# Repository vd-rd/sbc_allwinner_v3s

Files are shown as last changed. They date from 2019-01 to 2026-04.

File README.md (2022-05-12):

# Allwinner V3s SBC

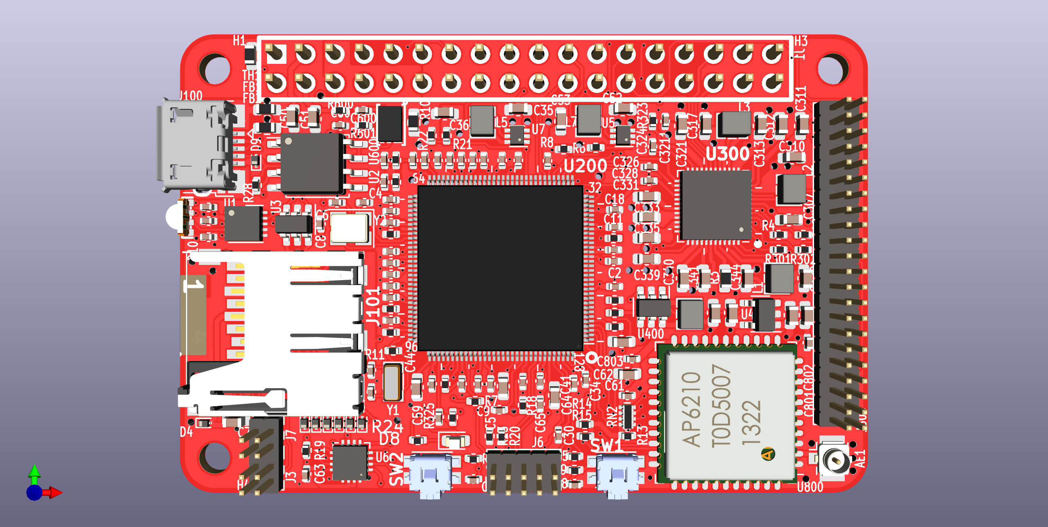
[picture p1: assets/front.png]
board_render


This board embeds a SIP (single core 1GHz Cortex-A7 with 64MB DDR2) with AXP203 PMIC, IO headers and microSD/eMMC storage.

Board overview (draft):
[TBD]

## Board features
| Characteristic | Description |
| --- | --- |
| Dimensions | 60mm x 40mm |
| Processor | Allwinner V3s Cortex-A7 @1GHz |
| Oscillators | 32.768kHz slow click, 24MHz main clock |
| RAM | 512Mb embedded DDR2 memory |
| Storage | SPI Flash/microSD |
| USB | 1 microUSB OTG |
| Ethernet | 10/100M PHY with pins on header |
| Supply | Power path between USB/Vin/Battery, 5V max |

## Notes and observations

### Expansions
The board features a number of connectors. They expose various buses for expansions:
 * 1 SPI port
 * 2 UART ports
 * 1 I2C port
 * 2 ADC enabled pins
 * 18bit parallel LCD interface
 * Ethernet signals with status LEDs

The connectors are organized in consistent locations present on the other SBCs i have developed.
 * J100 connector - 2.54mm 2x18 header with standard Apollo IoT pinout
 * J200 connector - 1.27mm 2x04 header with ethernet signals
 * J300 connector - 1.27mm 2x05 header with analog audio I/O signals
 * J500 connector - 1.27mm 2x20 header with parallel LCD interface signals

Check expansions section for example daughter cards with added functionality

### Boot process
The board has two boot strategies depending on component configuration. If the SPI flash memory is not used, the BROM uses the MicroSD as boot source and loads UBoot from there.
If the SPI flash is populated, UBoot with a minimal Kernel and Busybox can be stored as recovery environment or main application.

### LCD connector
Most of port D signals are mapped to the LCD connector. if LCD is not used they can be muxed as GPIO or other functions upon editing the DT overlay.

### AXP203
AXP203 is pin to pin compatible with the more popular AXP209, so they can be easily swapped.

### 1.2V Rail
Two different 1.2V rails are provided to the CPU. This is a deliberate decision to allow fixed CPU internal rail at 1.2V and provide DVFS cappability to 1.2V rail for CPU core.

### Signals on headers
All the signals on the headers, with their initial functions are detailed on the silkscreen on the bottom layer

### Battery usage
The board schematic uses a Diodes AP9211 battery protection IC for safety protections when used toghether with a LiIon battery. If a battery pack with embedded protection and thermistor is used, TH1 and AP9211 can be left unpopulated.

### Expansions
 The board can be combined with several predefined capes that add functionality.
 * [LCD cape](https://github.com/vd-rd/hw_cape_lcd) can be used to add a 3inch LCD/Touch with 800x480px resolution.
 * [GPS cape](https://github.com/vd-rd/hw_cape_gps) adds GPS/GNSS/GLONAS capabilities
 * [GSM cape](https://github.com/vd-rd/hw_cape_gsm) adds GPRS connectivity. 

## Resources
You can find all necesary information to build or evaluate the module here:
   - [View 3D board render](https://a360.co/2GTPupk)
   - [Fabrication files](https://github.com/vd-rd/sbc_alw_v3s/releases)

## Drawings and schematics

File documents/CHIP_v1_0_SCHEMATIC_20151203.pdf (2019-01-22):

# Schematics Index：

# P01: REVISION HISTORY

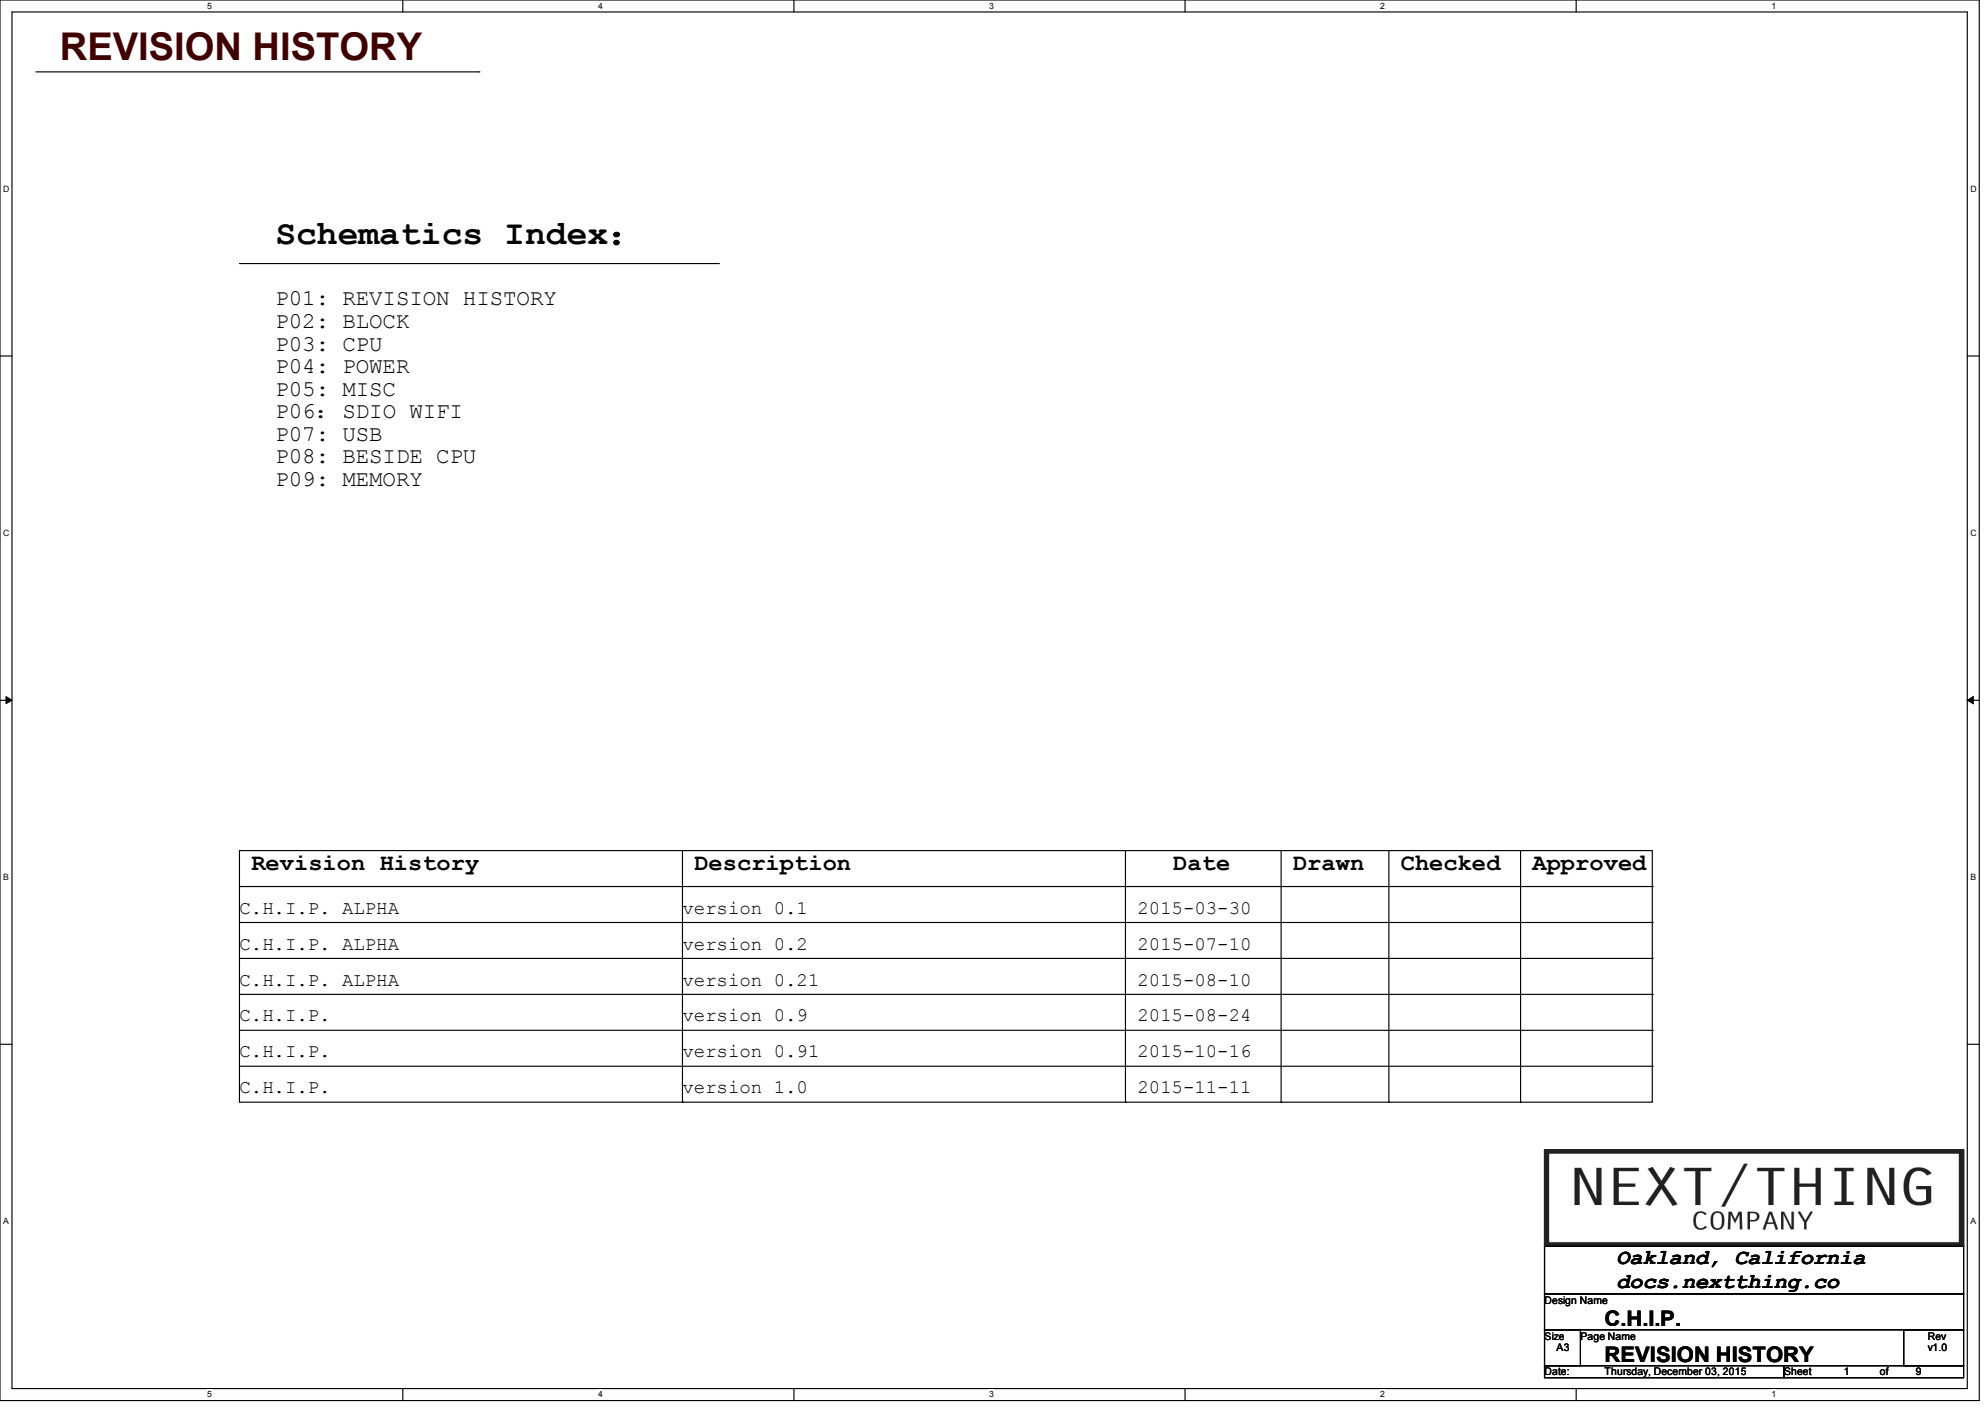
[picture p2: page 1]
Revision History; Description; Date; Drawn; Checked; Approved; P02: BLOCK P03: CPU P04: POWER P05: MISC P06：SDIO WIFI; P07: USB P08: BESIDE CPU P09: MEMORY; REVISION HISTORY; C.H.I.P. ALPHA; version 0.1; version 0.2; version 0.21; version 0.9; version 0.91; version 1.0; Design Name; Size; Page Name; Rev; Date:; Sheet; Thursday, December 03, 2015

Oakland, California
docs.nextthing.co

# BATT

# DCIN

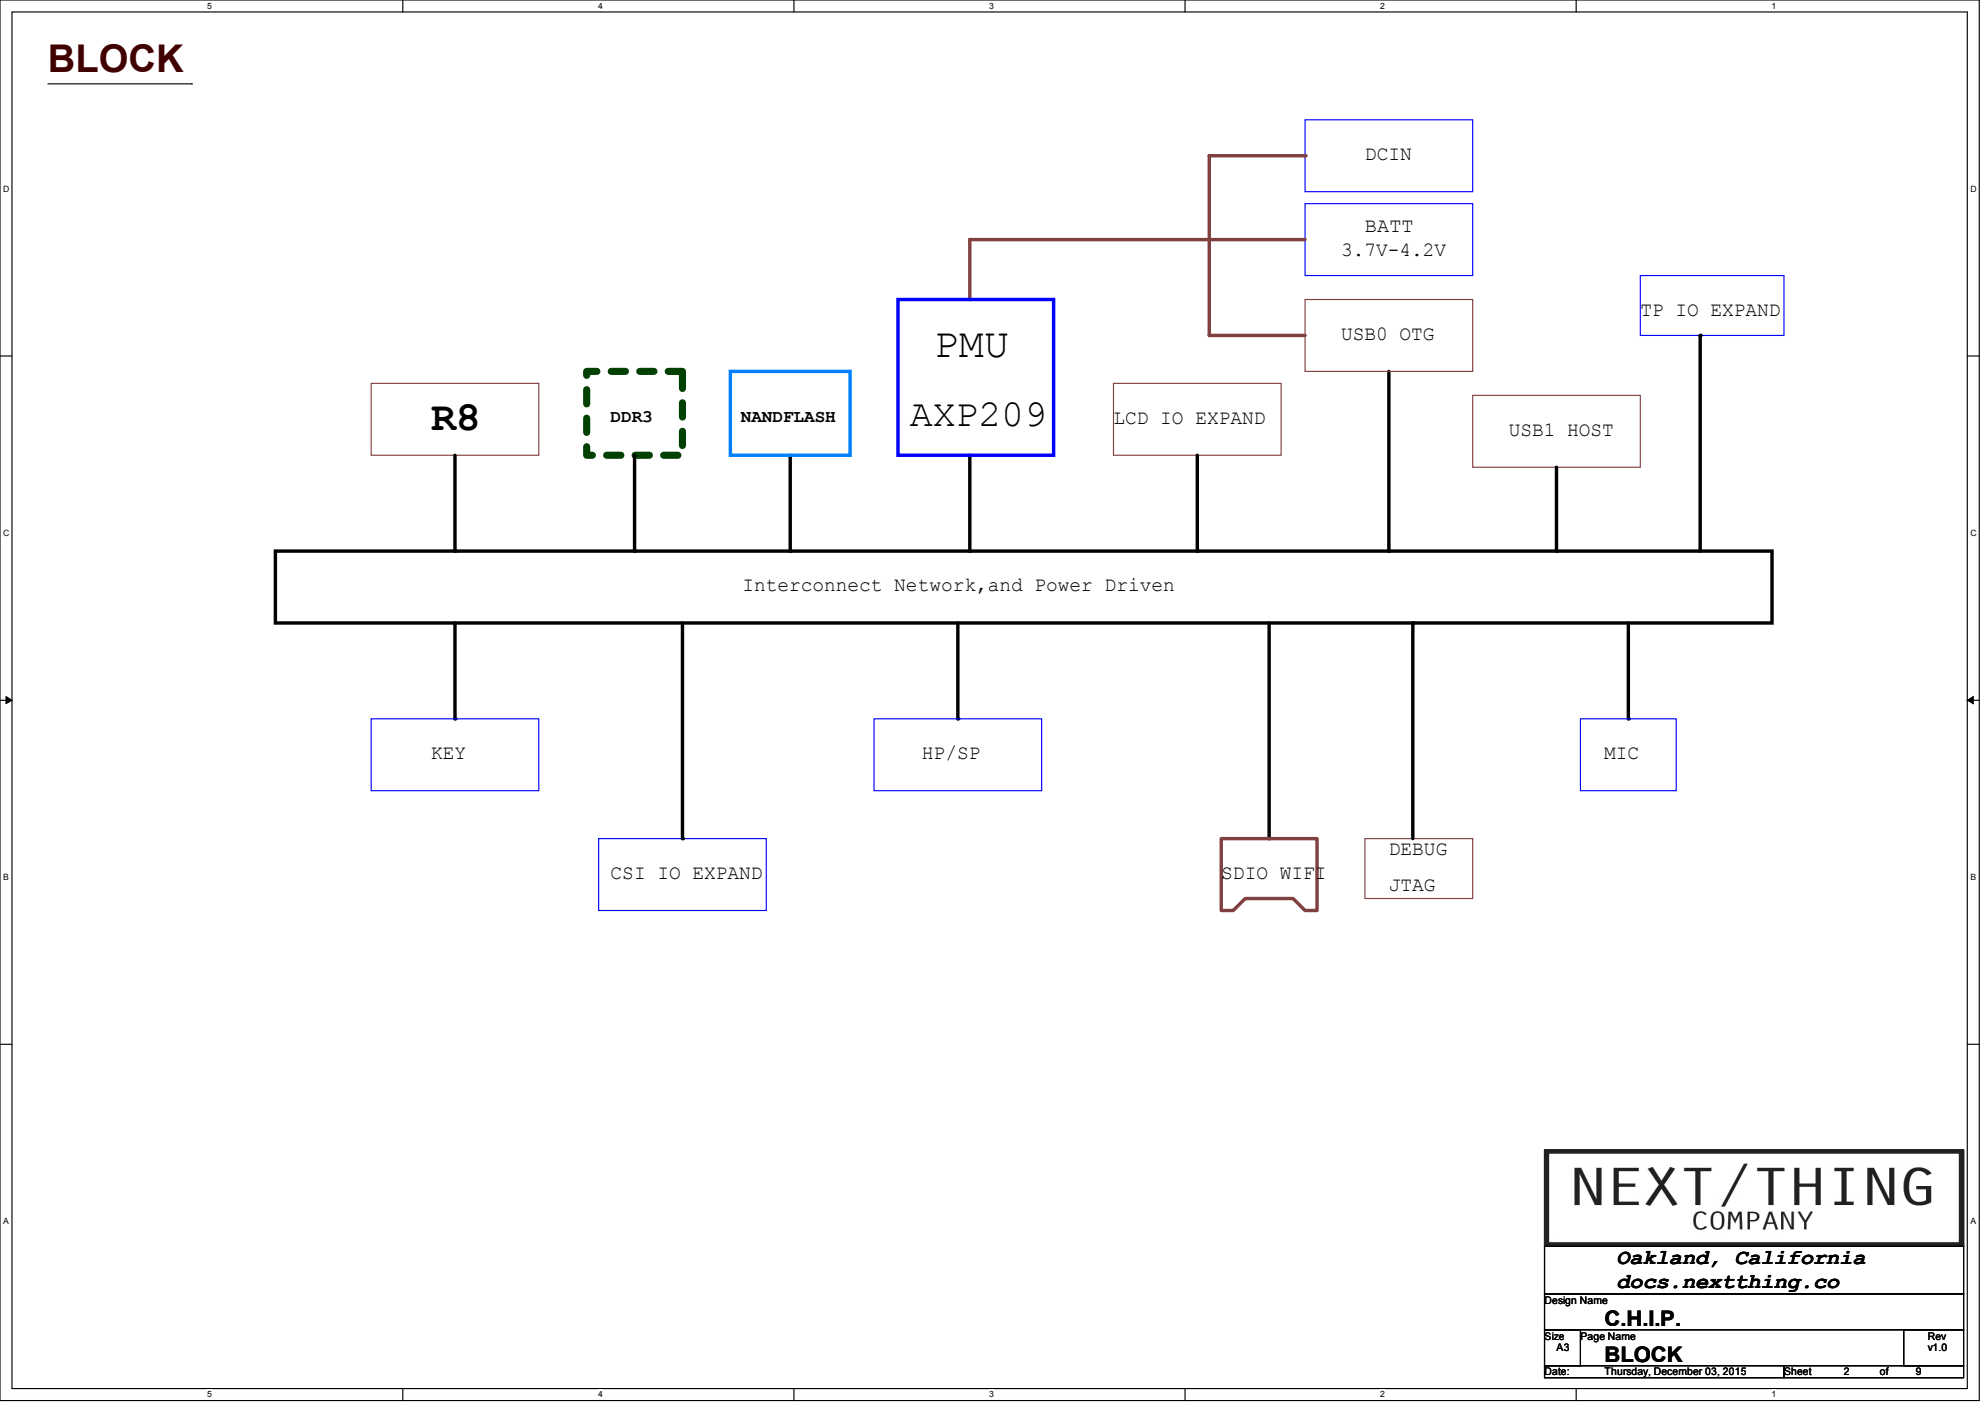
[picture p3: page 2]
SDIO WIFI; USB0 OTG; DEBUG; JTAG; KEY; PMU; AXP209; MIC; BLOCK; NANDFLASH; USB1 HOST R8; DDR3; Thursday, December 03, 2015

TP IO EXPAND

LCD IO EXPAND

Interconnect Network,and Power Driven

CSI IO EXPAND

Oakland, California
docs.nextthing.co

# CPU

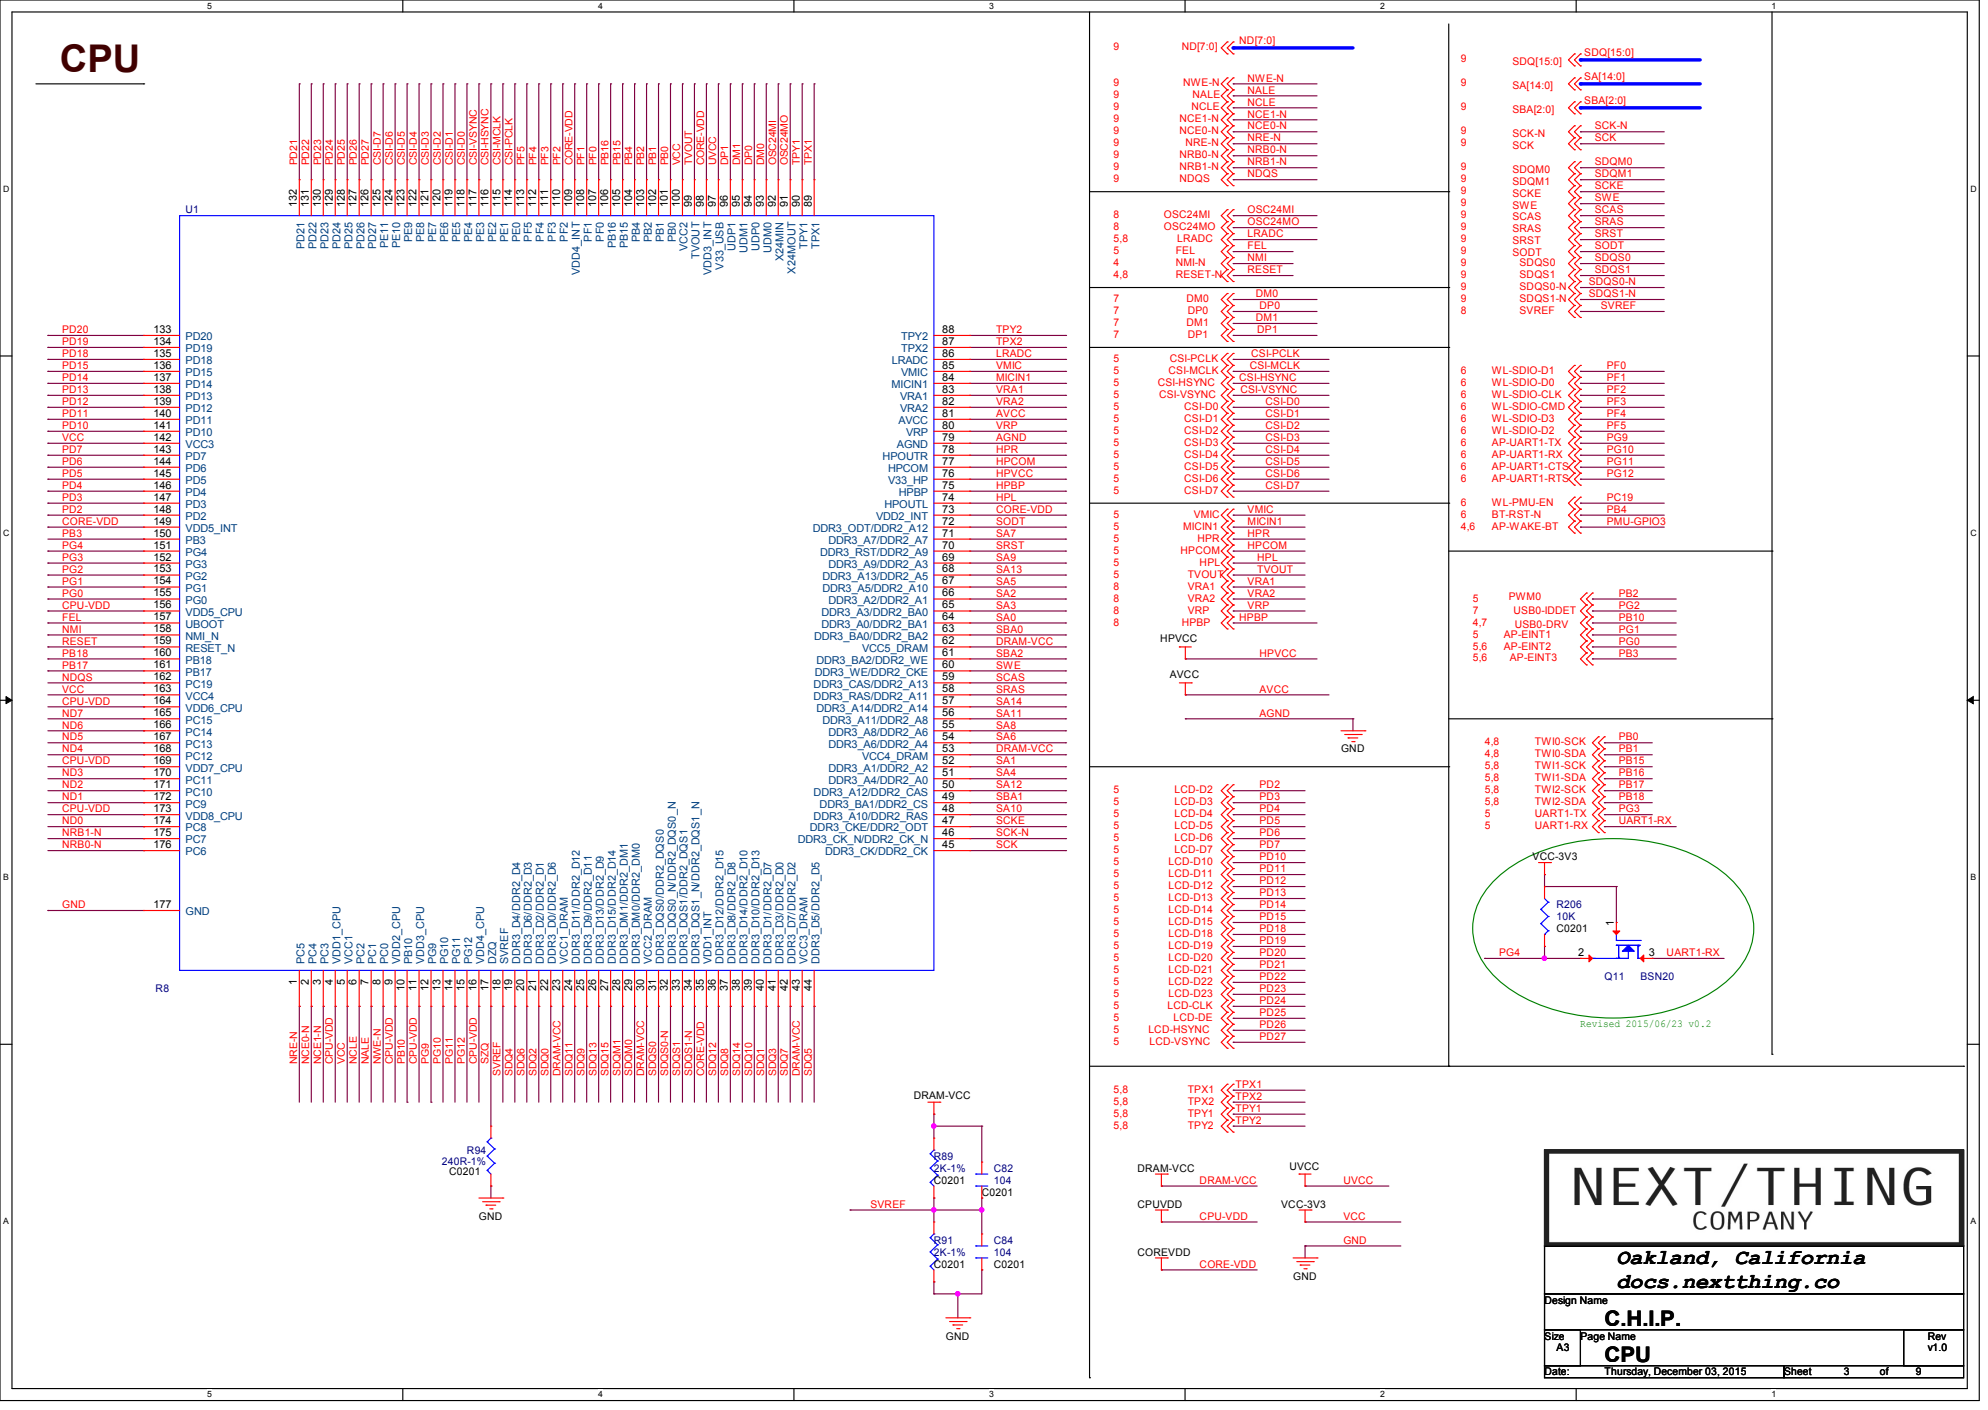
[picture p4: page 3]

# POWER/PMU

# IPSOUT TO 5V FOR SYS

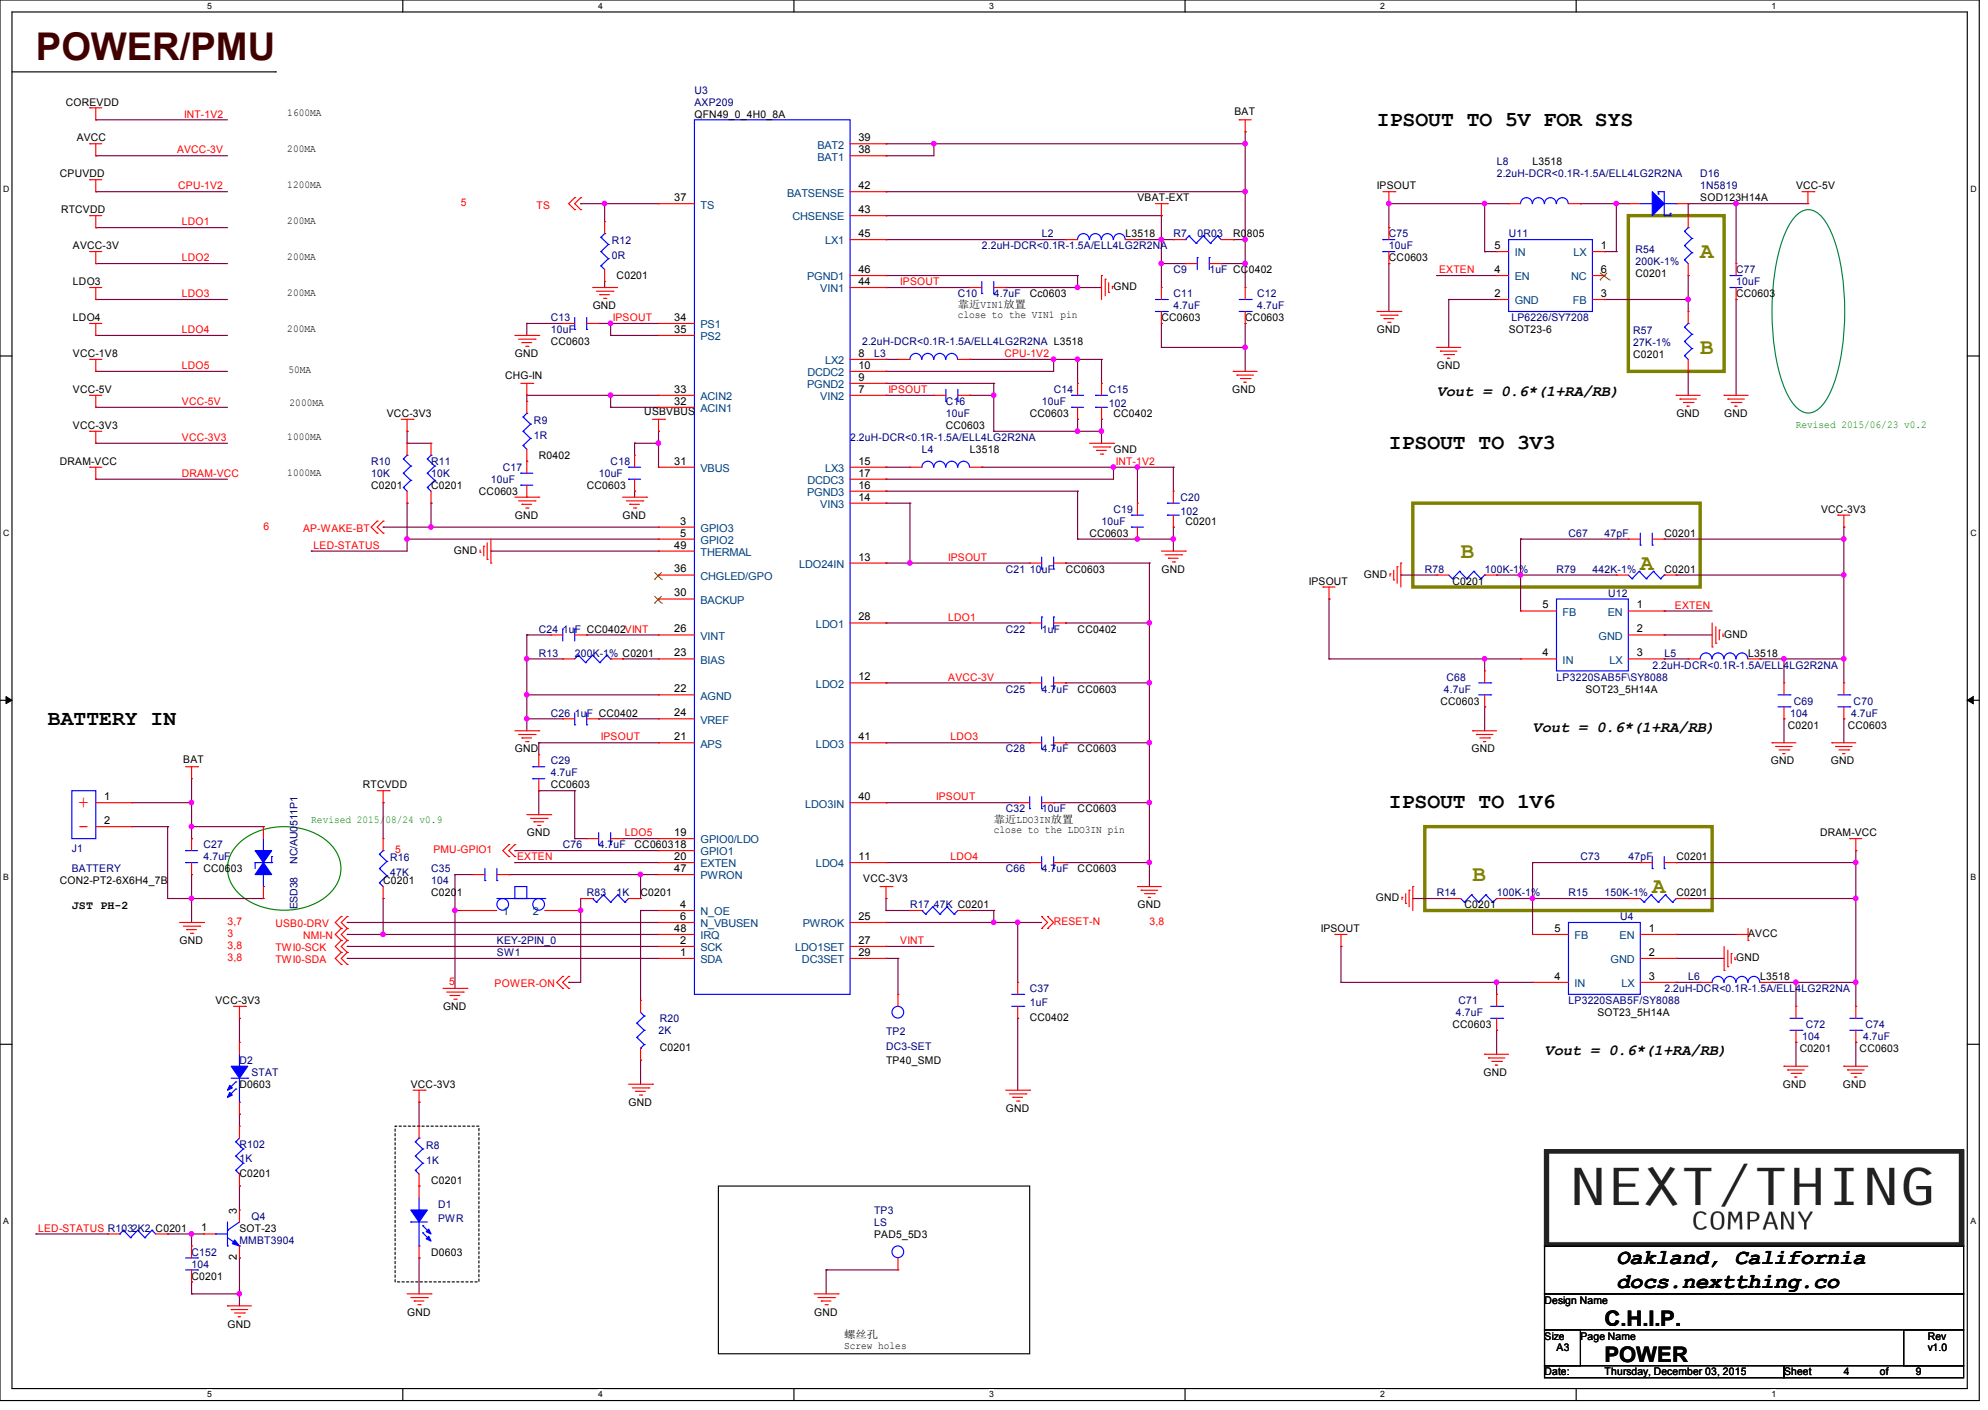
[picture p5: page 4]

靠近VIN1放置
close to the VIN1 pin

靠近LDO3IN放置
close to the LDO3IN pin

# MISC

## Note:

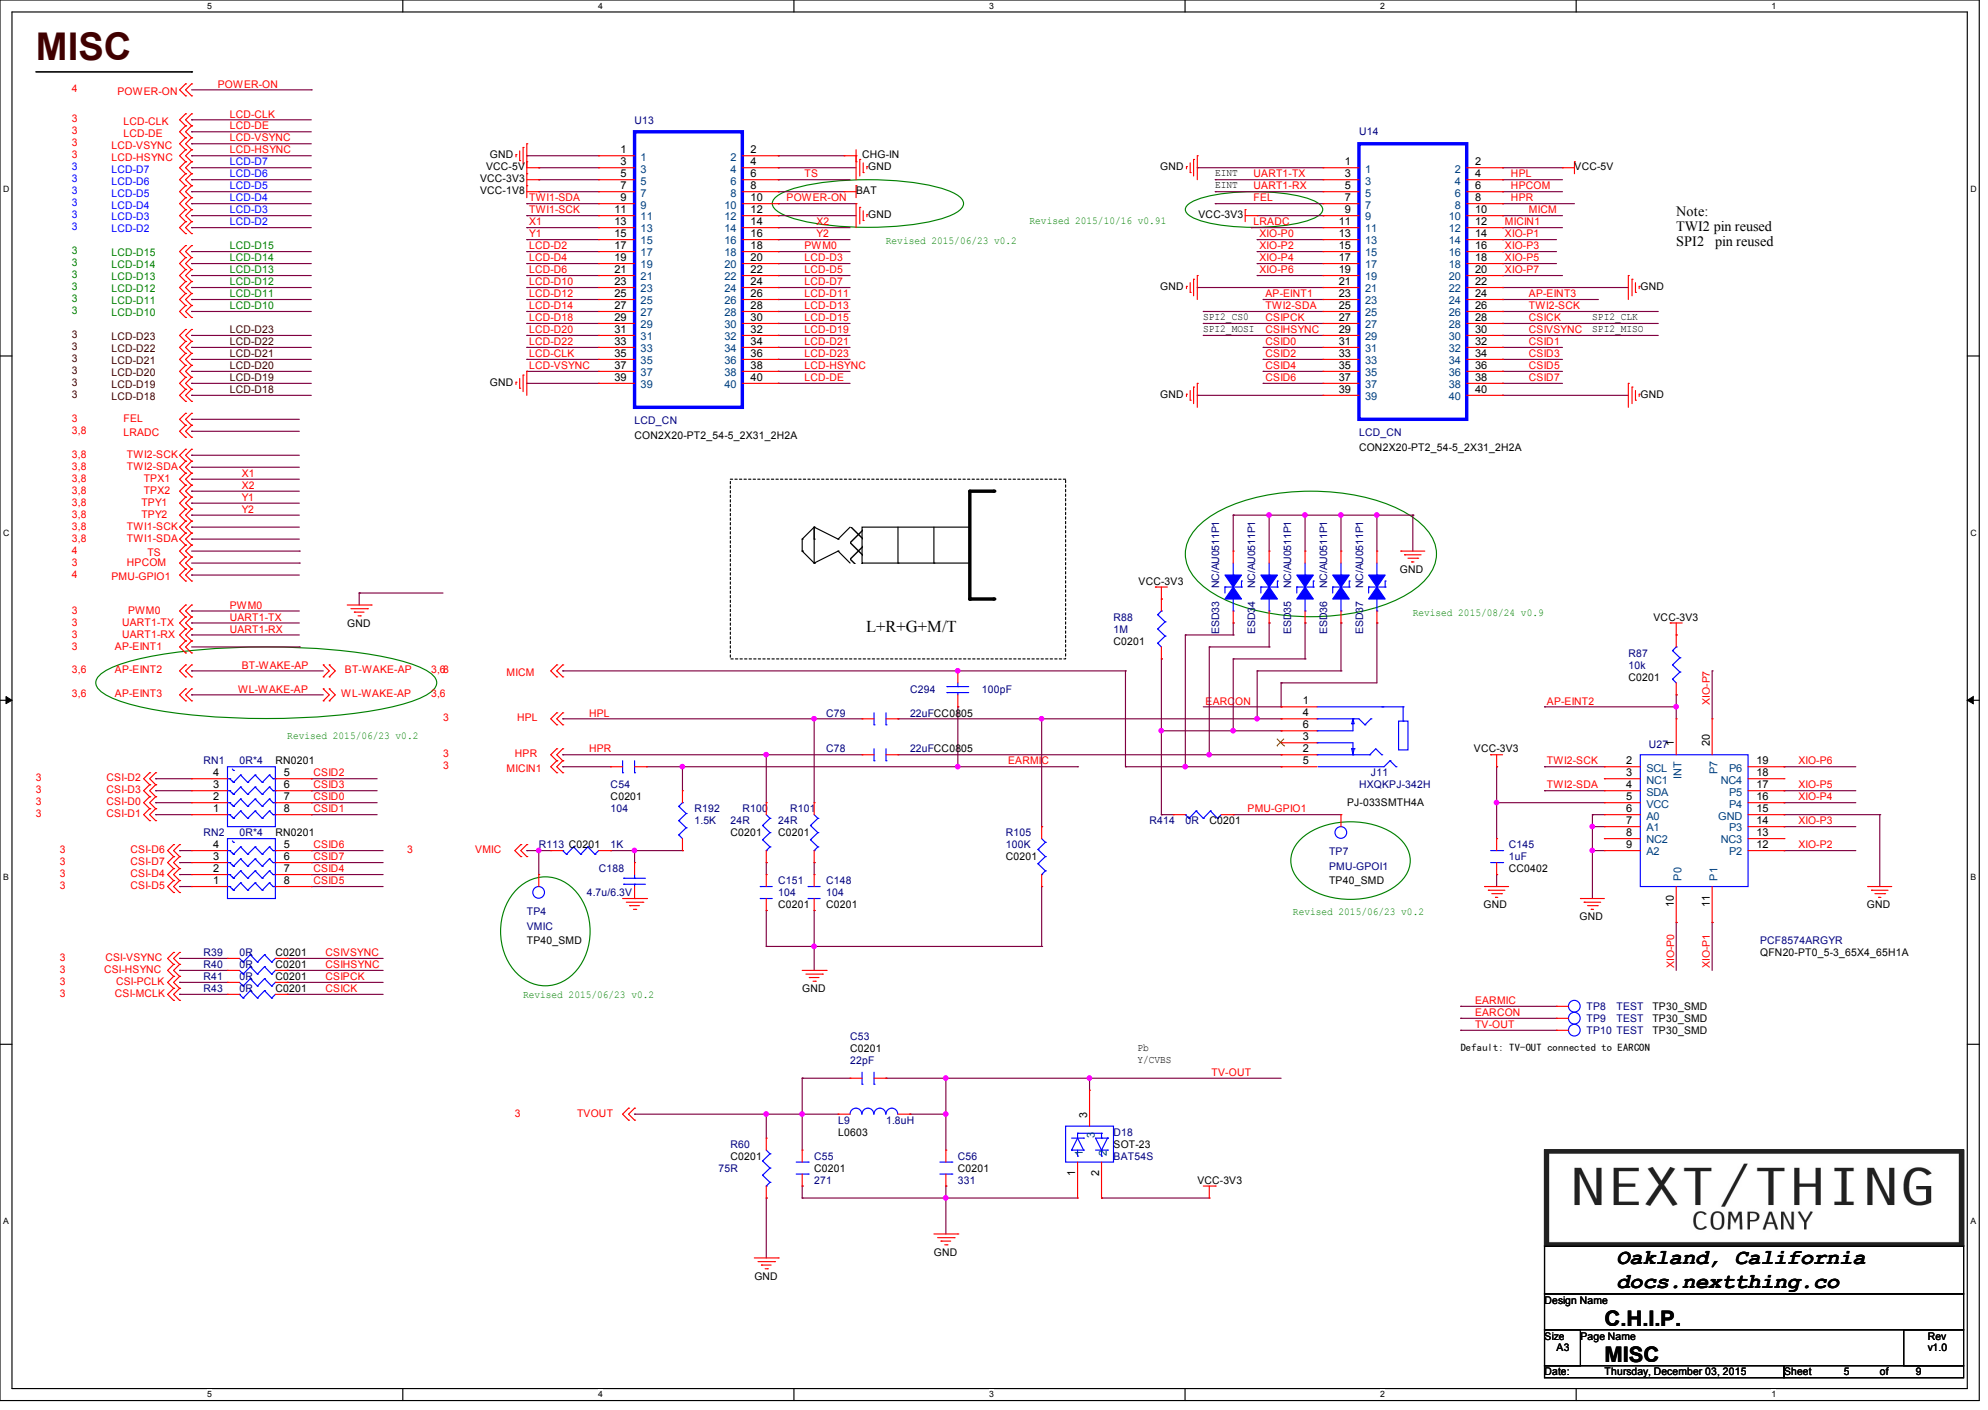
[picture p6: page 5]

EARMIC | | 6

Default: TV-OUT connected to EARCON

A

B

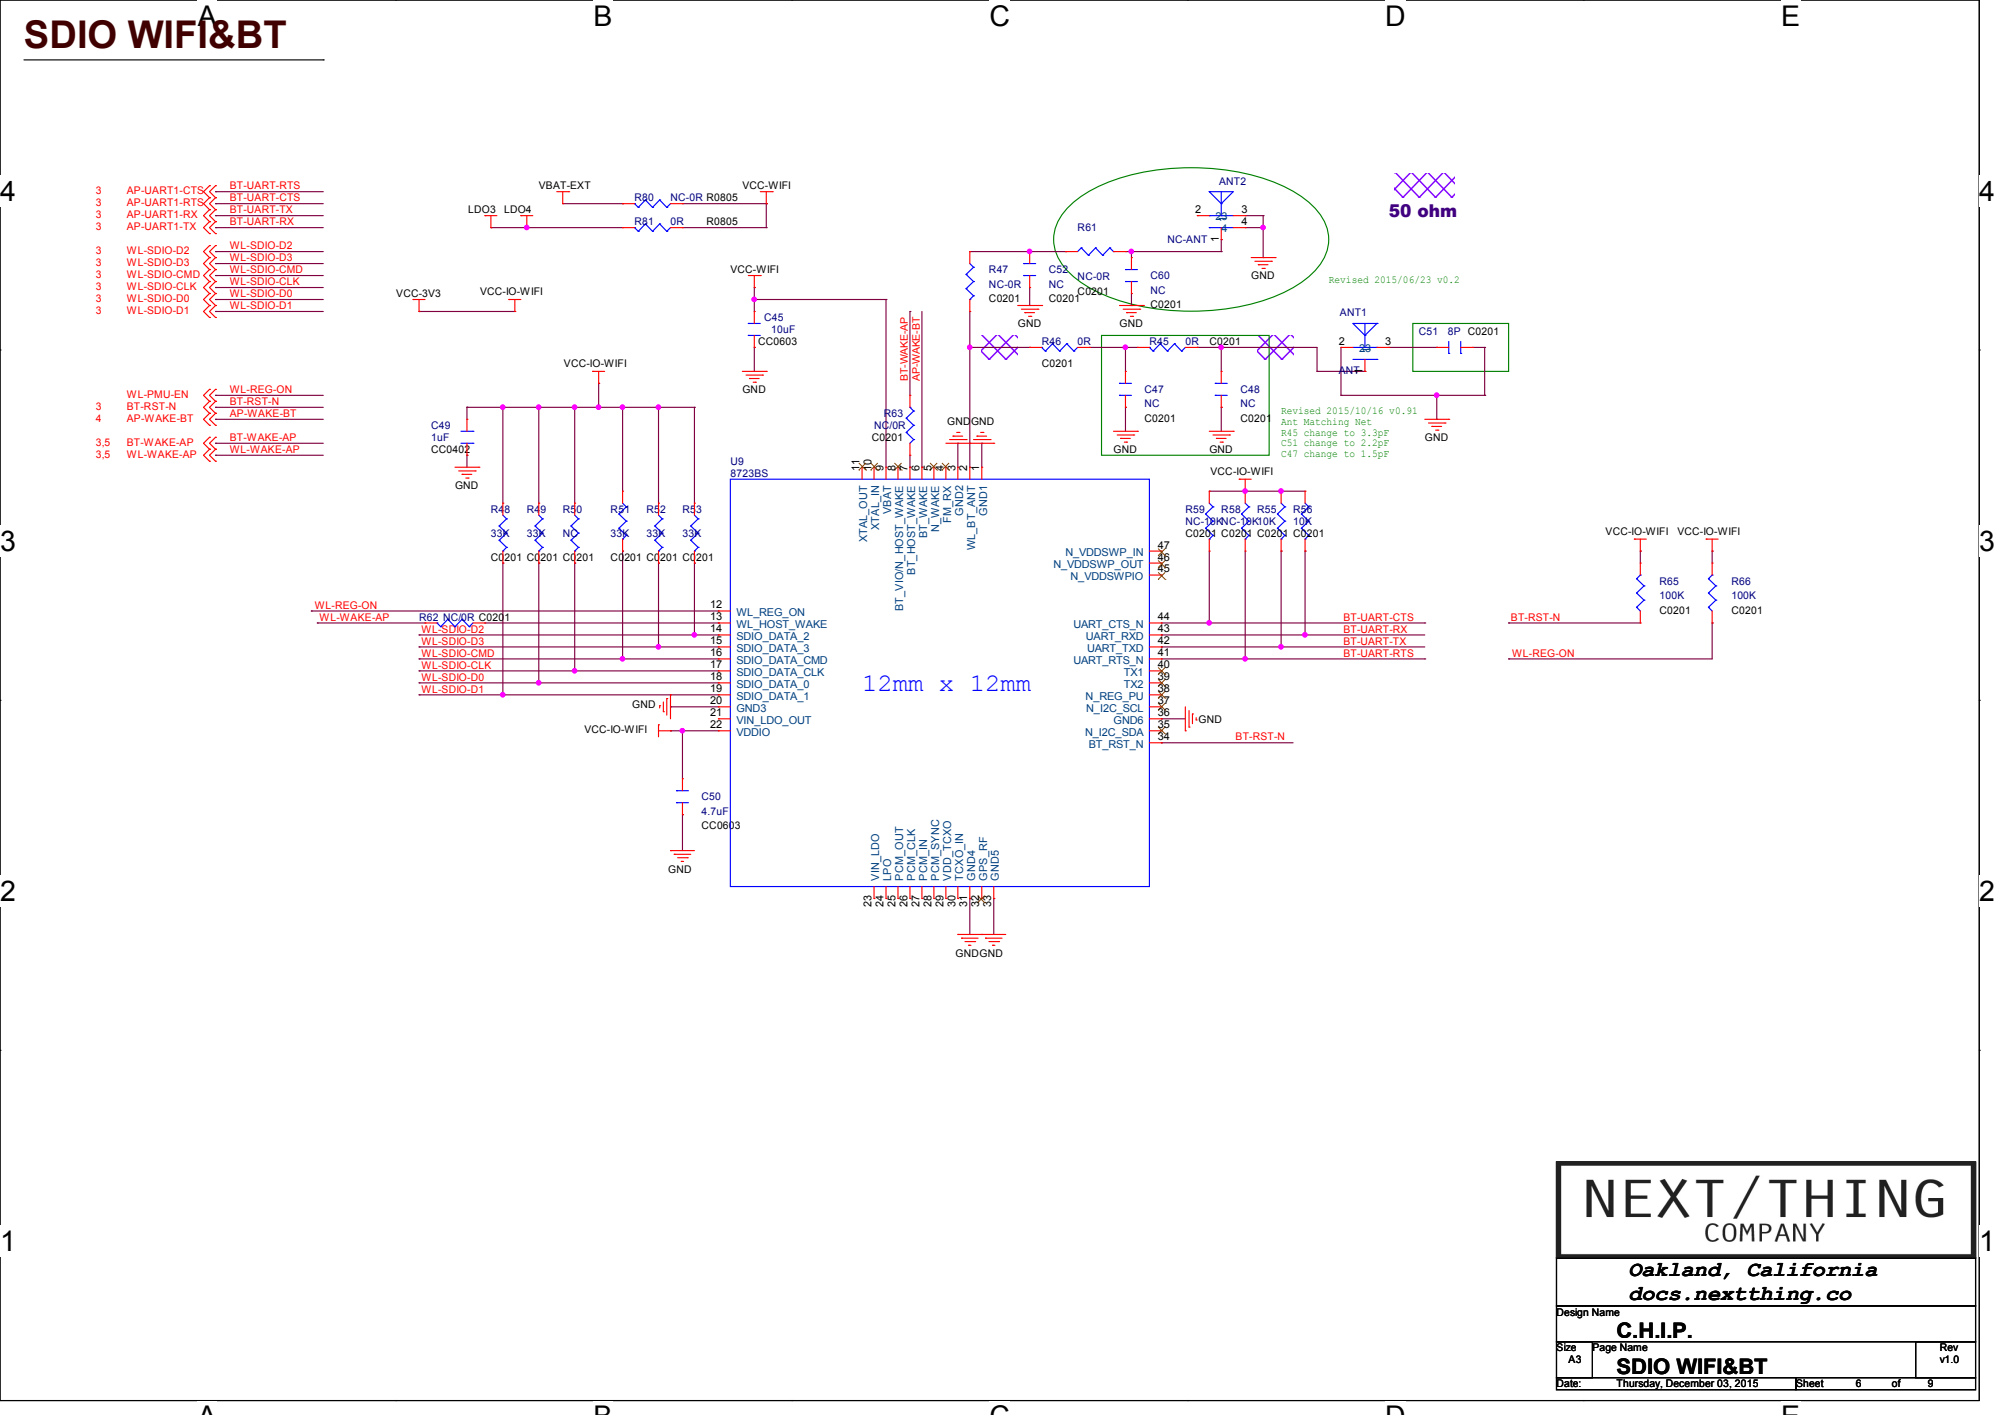
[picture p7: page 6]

VCC-IO-WIFI

# USB

# USB

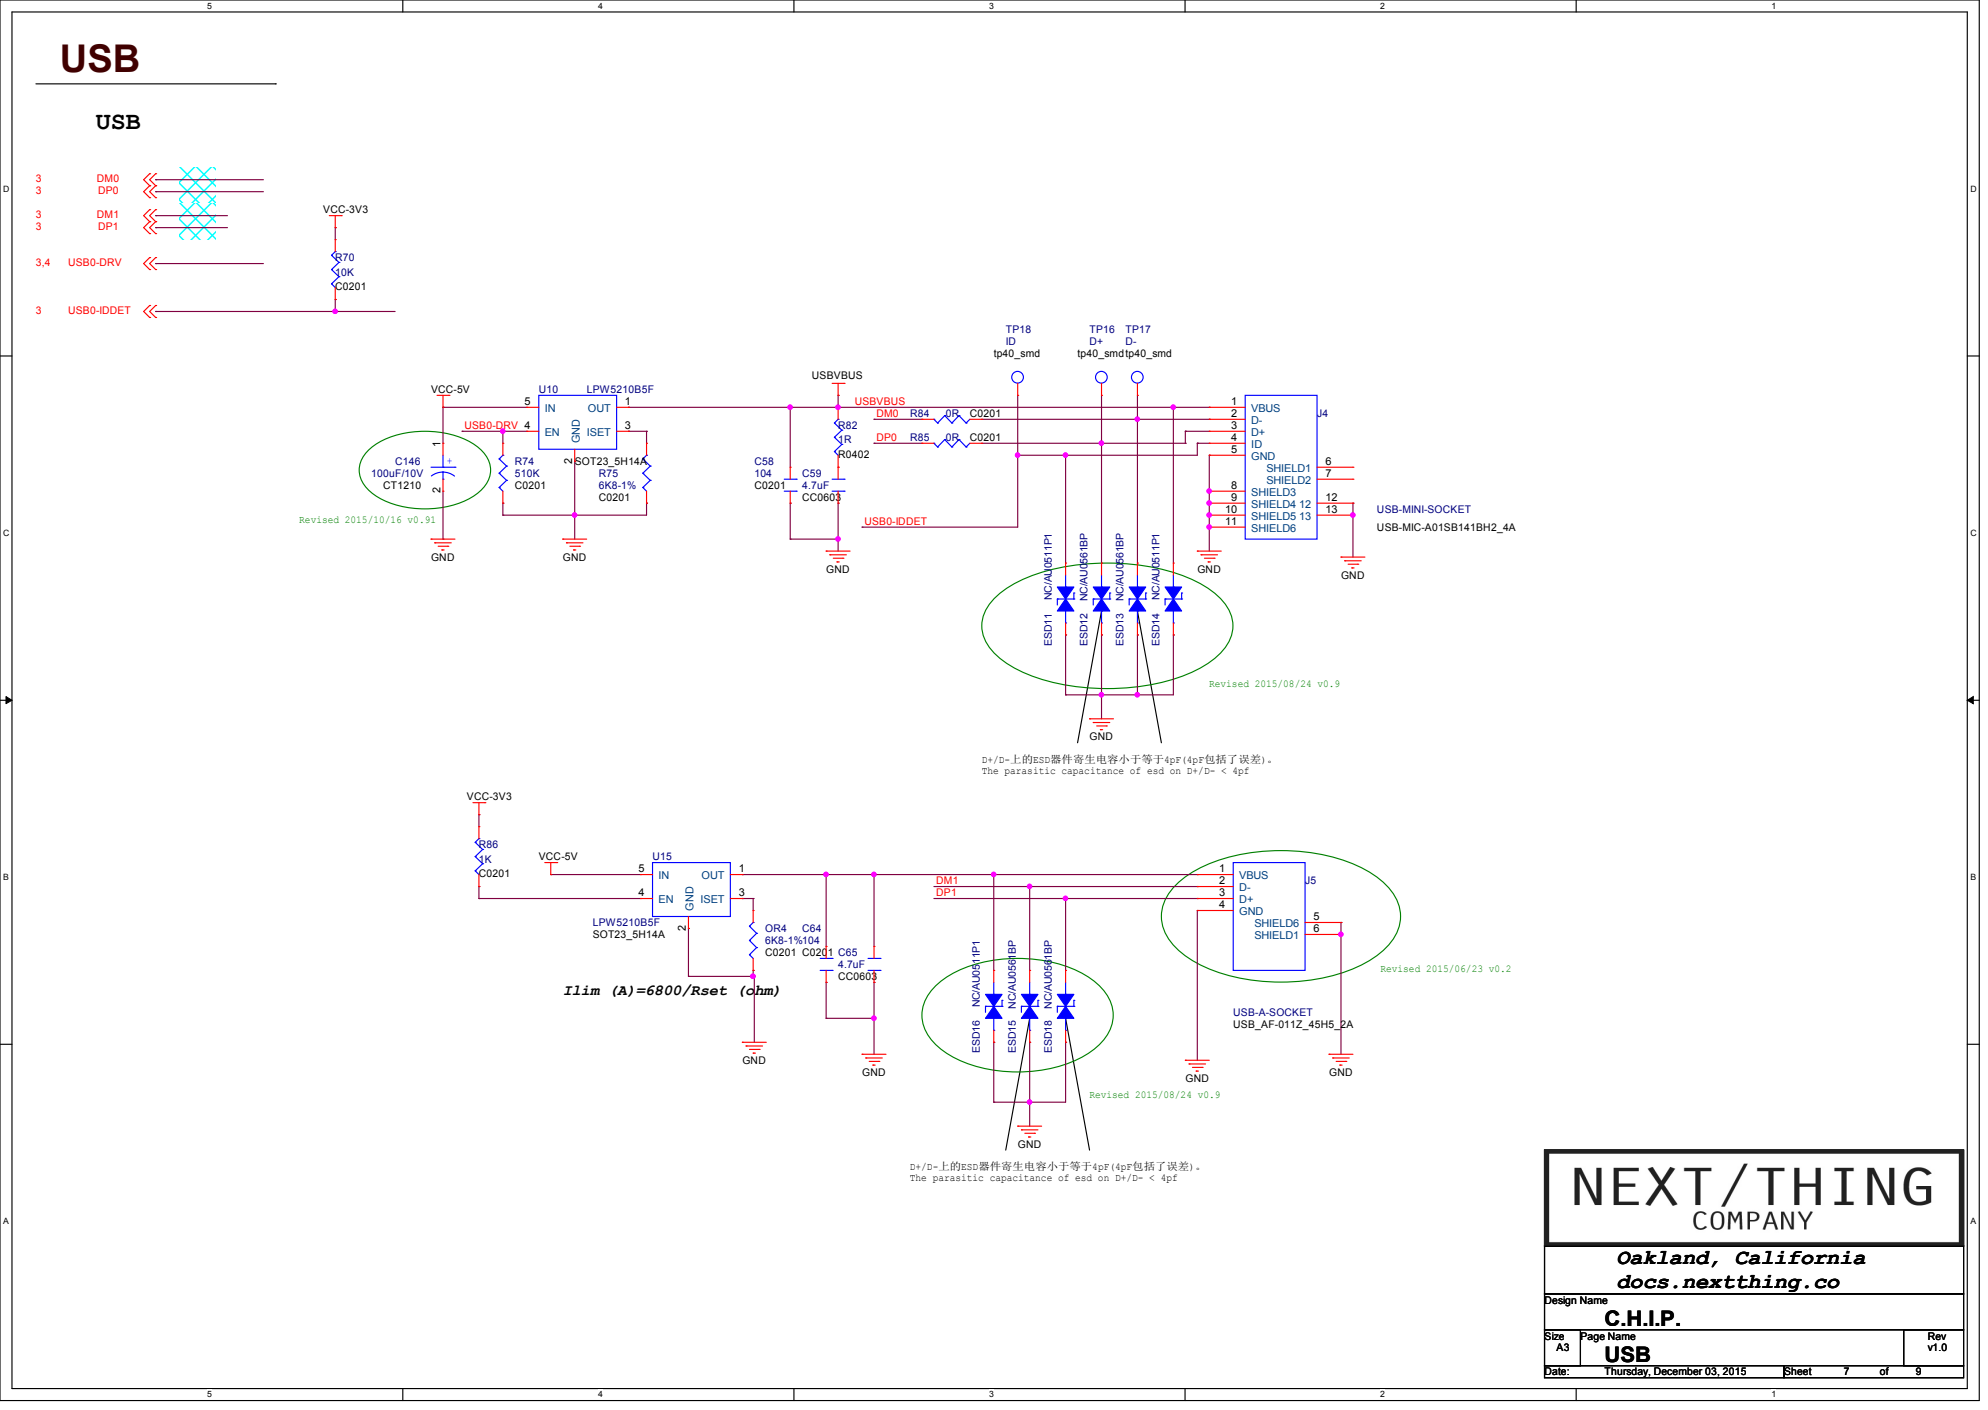
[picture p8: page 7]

D+/D-上的ESD器件寄生电容小于等于4pF(4pF包括了误差)。
The parasitic capacitance of esd on D+/D- < 4pf

# DRAM

# PIO-INTFACE

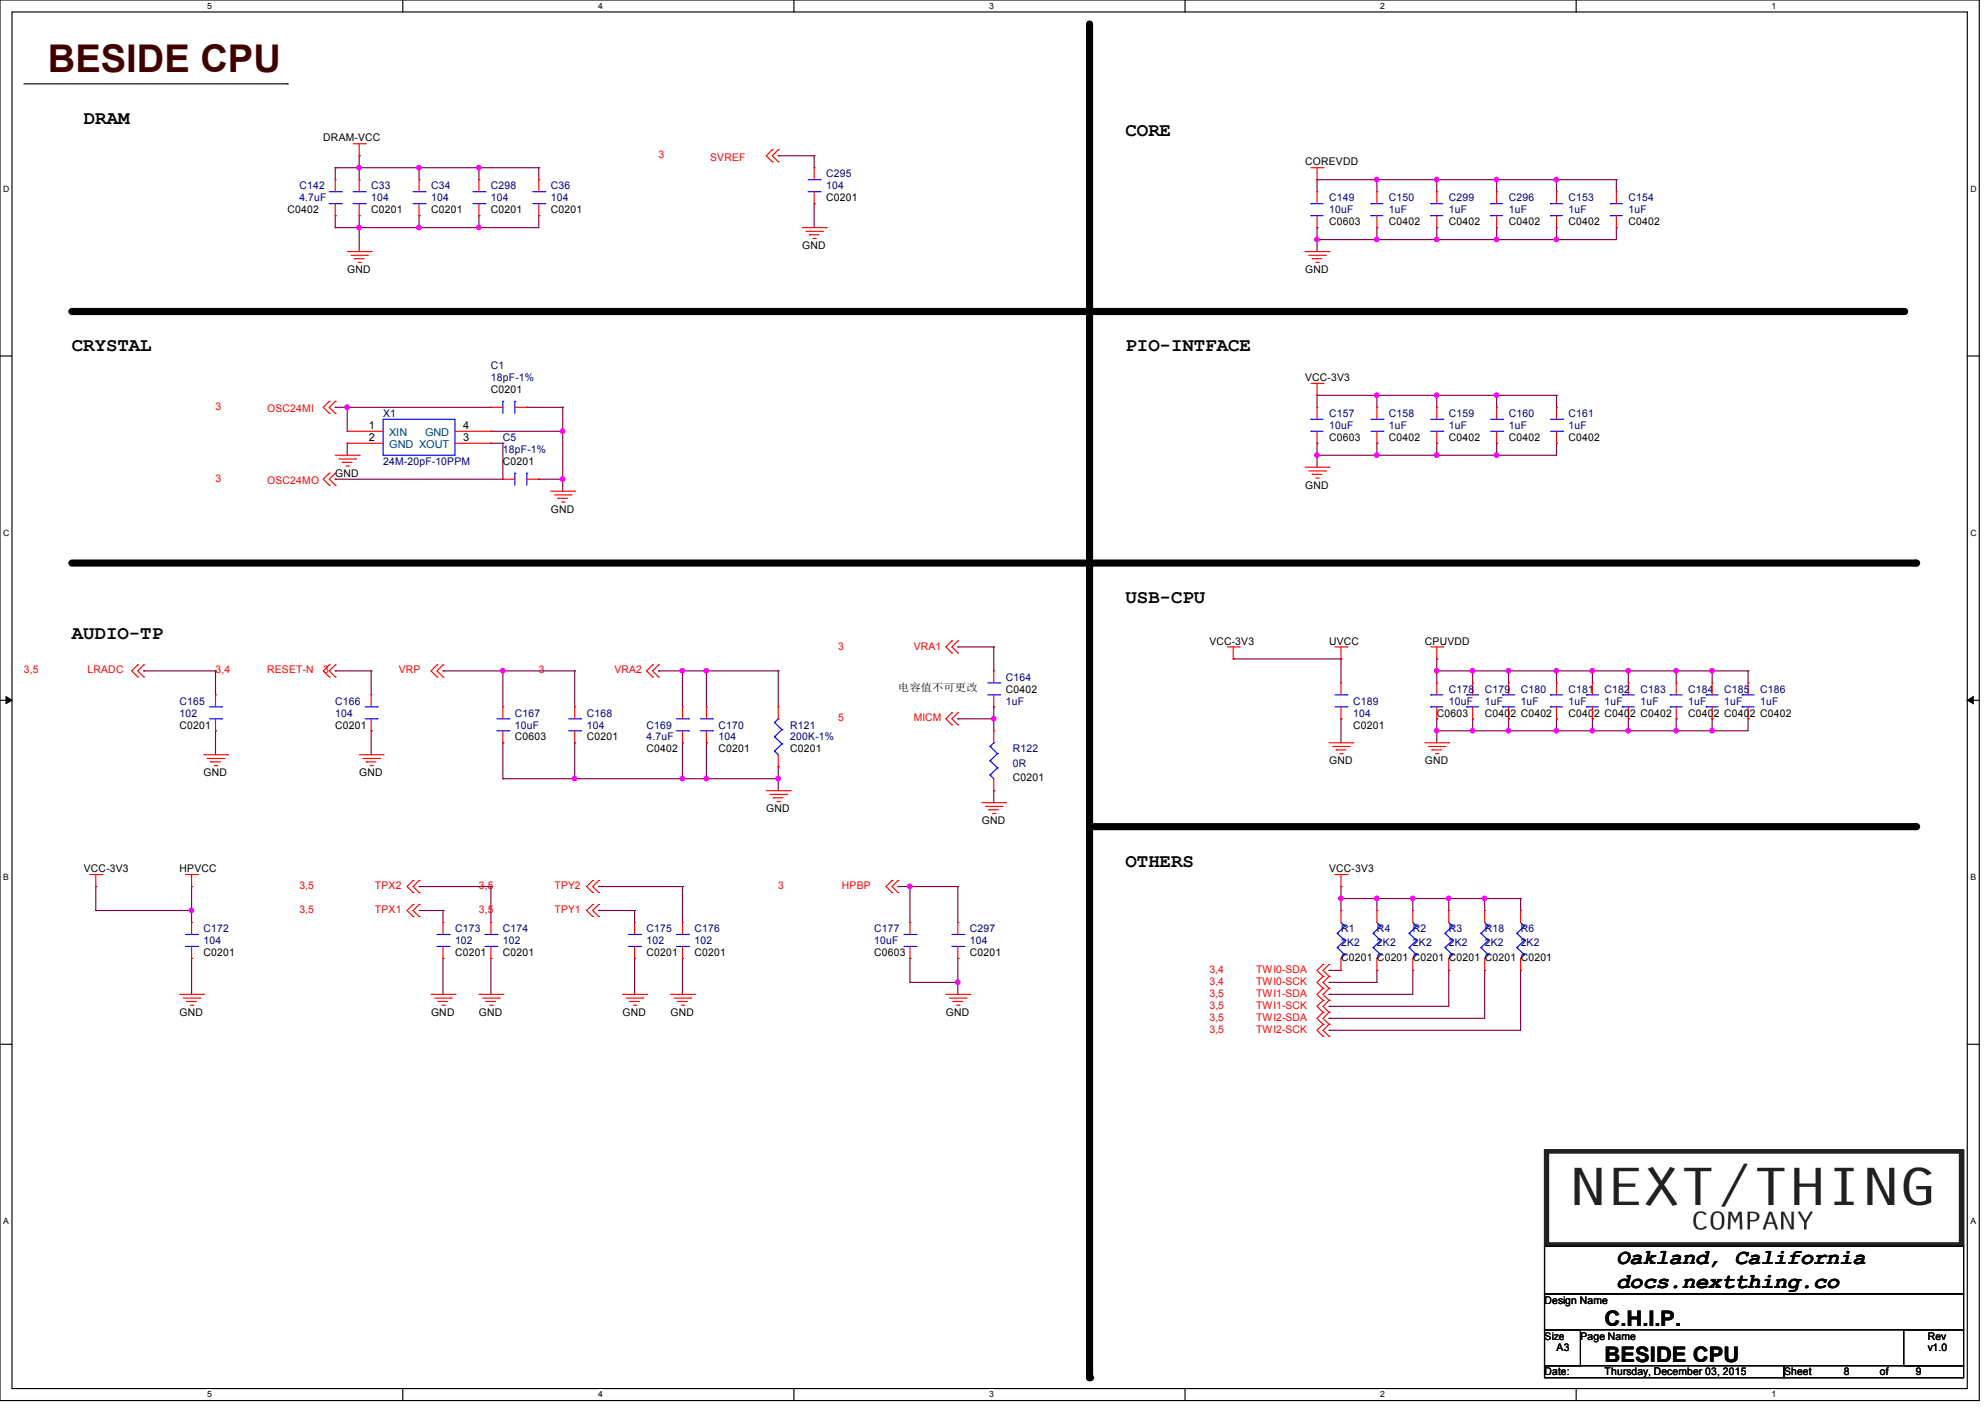
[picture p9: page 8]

# MEMORY

DDR3 | NAND

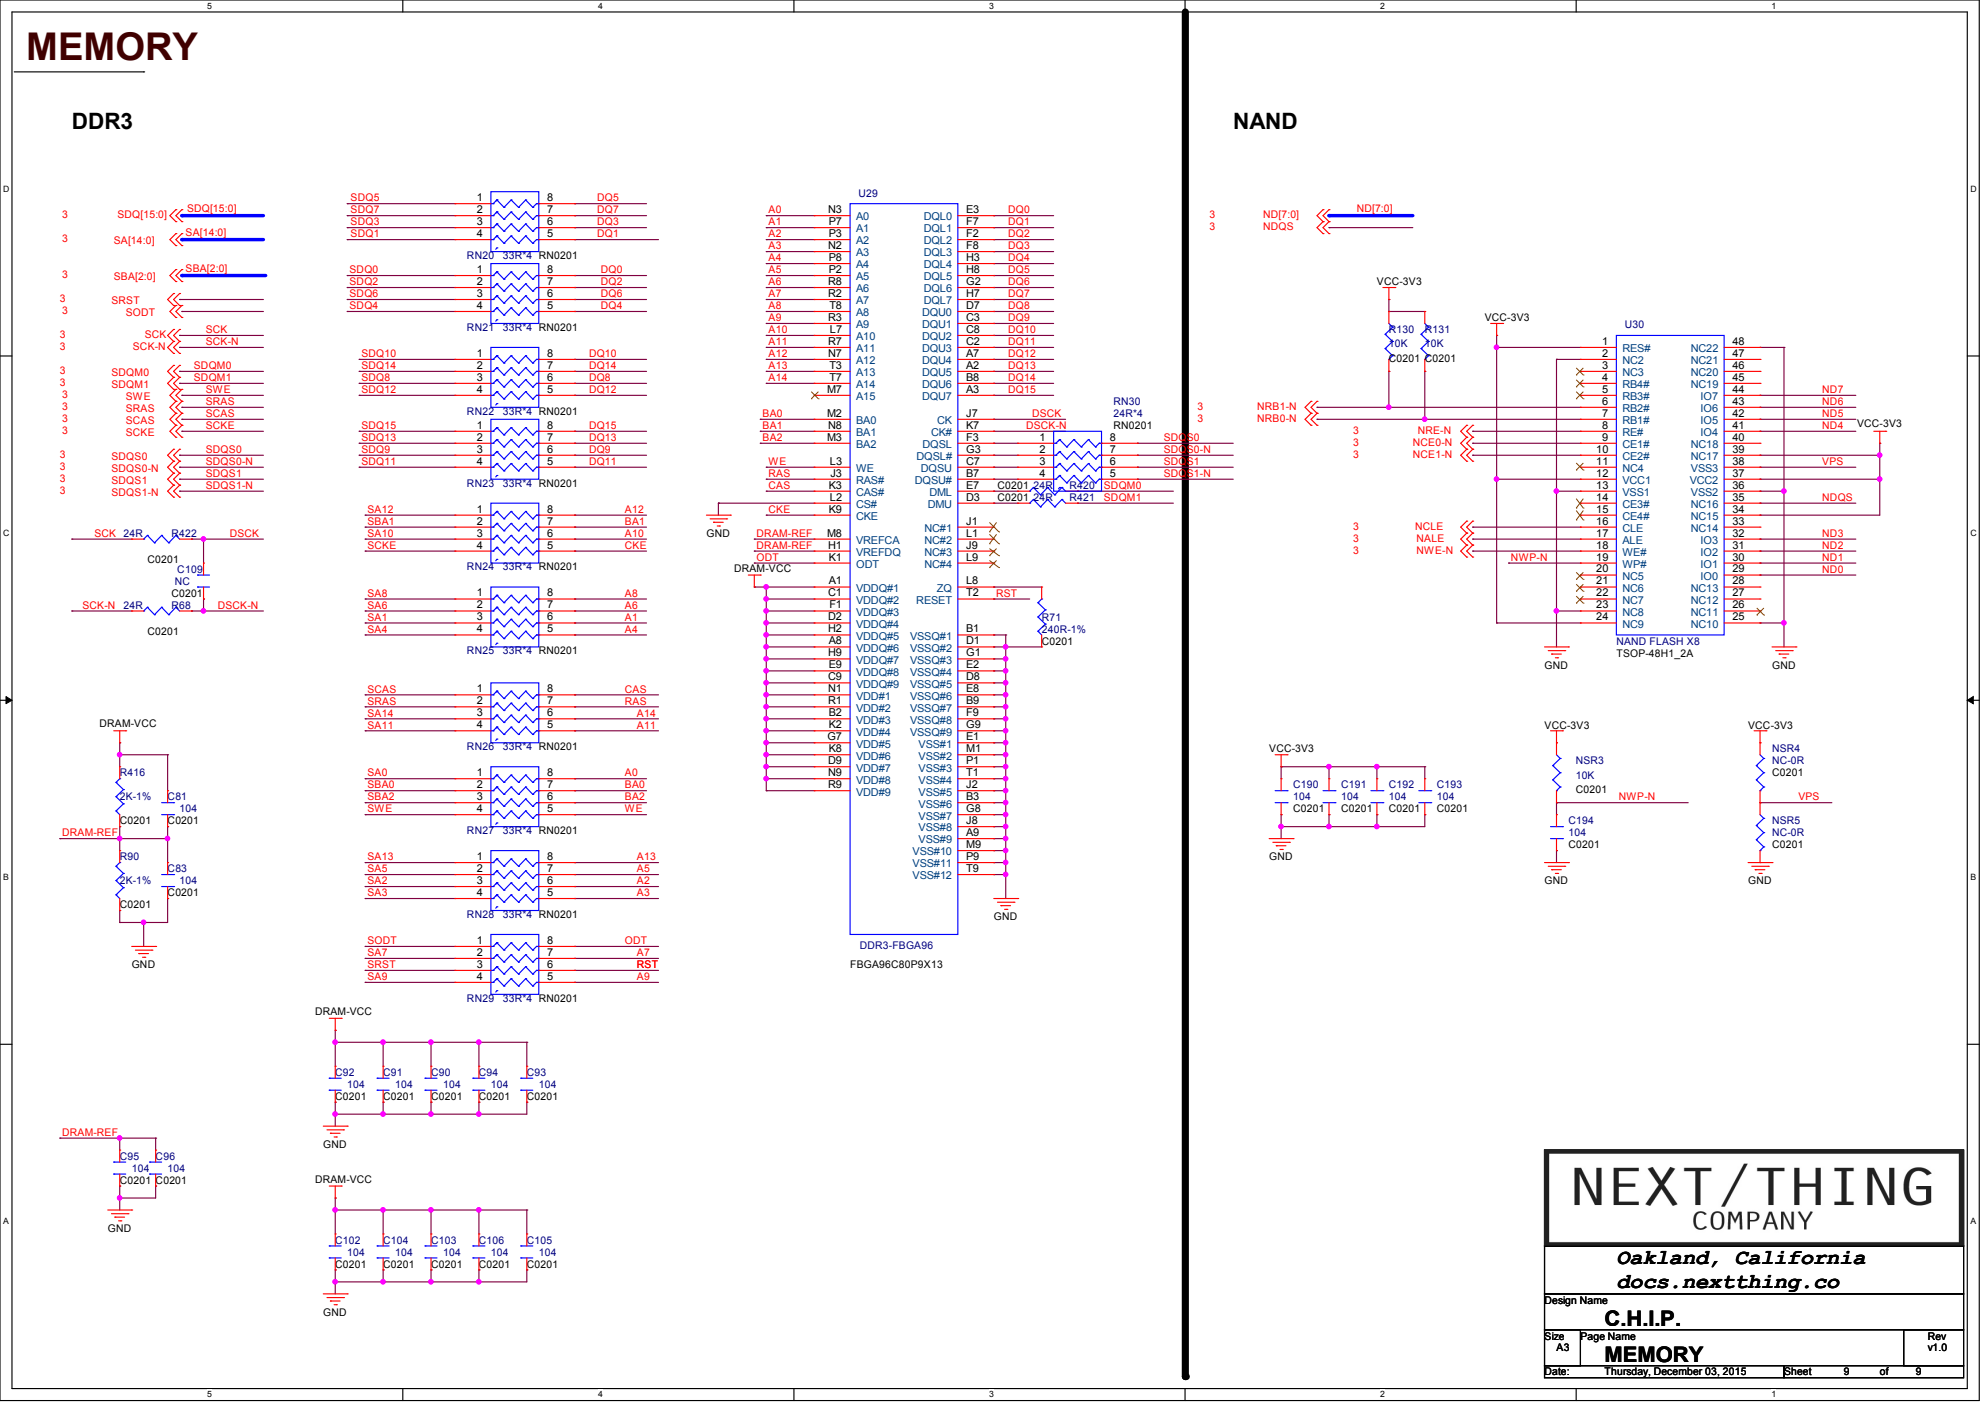
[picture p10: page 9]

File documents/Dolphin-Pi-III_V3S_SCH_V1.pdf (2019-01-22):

# Schematics Index：

# P01: REVISION HISTORY P02: BLOCK P03: POWER TREE P04: GPIO ASSIGNMENT P05: CPU P06: POWER P07: CAMERA-MIPI P08: RGB LCD 2.7 P09: NOR NANDFlash/TF Card P10: SPEAKER/MICROPHONE/HEADPHONE P11: USB/KEY/GSENSOR P12: OPTION:RGB LCD 4.3 /CTP/GPS

# REVISION HISTORY

Ver 1.1 | changelist.txt | 2015-08-17 | WJW HW
Revision | Description | Date | Drawn | Checked
Ver 0.1 | Initial | 2015-02-04

Design Name

Size A3 | Page Name REVISION HISTORY REVISION HISTORY REVISION HISTORY | Rev
Date: Sunday, October 22, 2017 Sunday, October 22, 2017 Sunday, October 22, 2017 | Sheet 1 1 1 of 12 12 12

# AllWinner Technology Co.,Ltd

## V3S_STD_CDR_V1_0

Design Name

# AllWinner Technology Co.,Ltd

## V3S_STD_CDR_V1_0

Design Name

# AllWinner Technology Co.,Ltd

## V3S_STD_CDR_V1_0

55

44

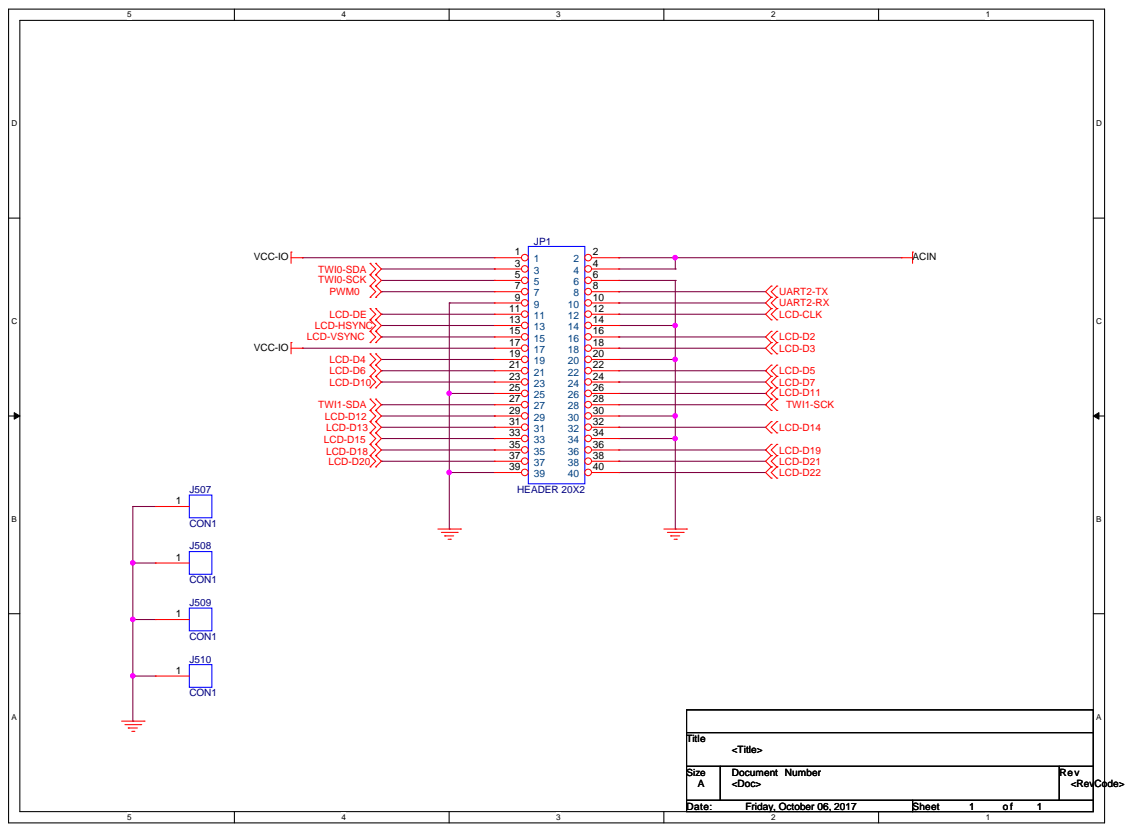
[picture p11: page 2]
VCC-IO; ACIN; WI1-SDA; LCD-D22; LCD-D20; LCD-D21 TWI1-SCK; LCD-DE LCD-HS; YNC; LCD-VS; YNC LCD-D4 LCD-D6 LCD-D10 LCD-D18 LCD-D15; WI0-SDA; WI0-SCK; LCD-D11; LCD-D12 LCD-D13; LCD-D14 LCD-D5; Title Size; men; mber; Rev; ate:; Sheet; Code>; Title>; rida; tober 06, 2017; J508 CON1; HEADER 20X2 1 1; J509 CON1; J507 CON1; J510 CON1

UART2
UART2-RX LCD-CLK LCD-D2 LCD-D3 LCD-D19 LCD-D7

D | D
VCC-EPHY | VCC-RJ45

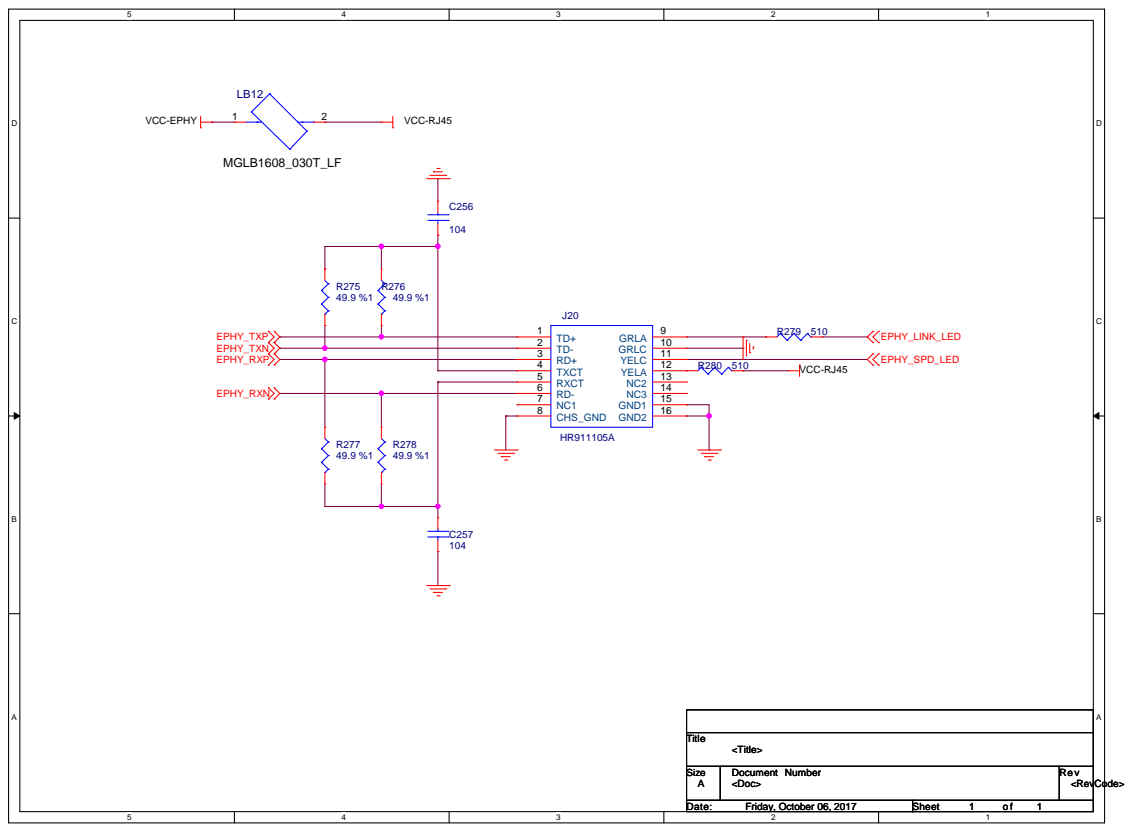
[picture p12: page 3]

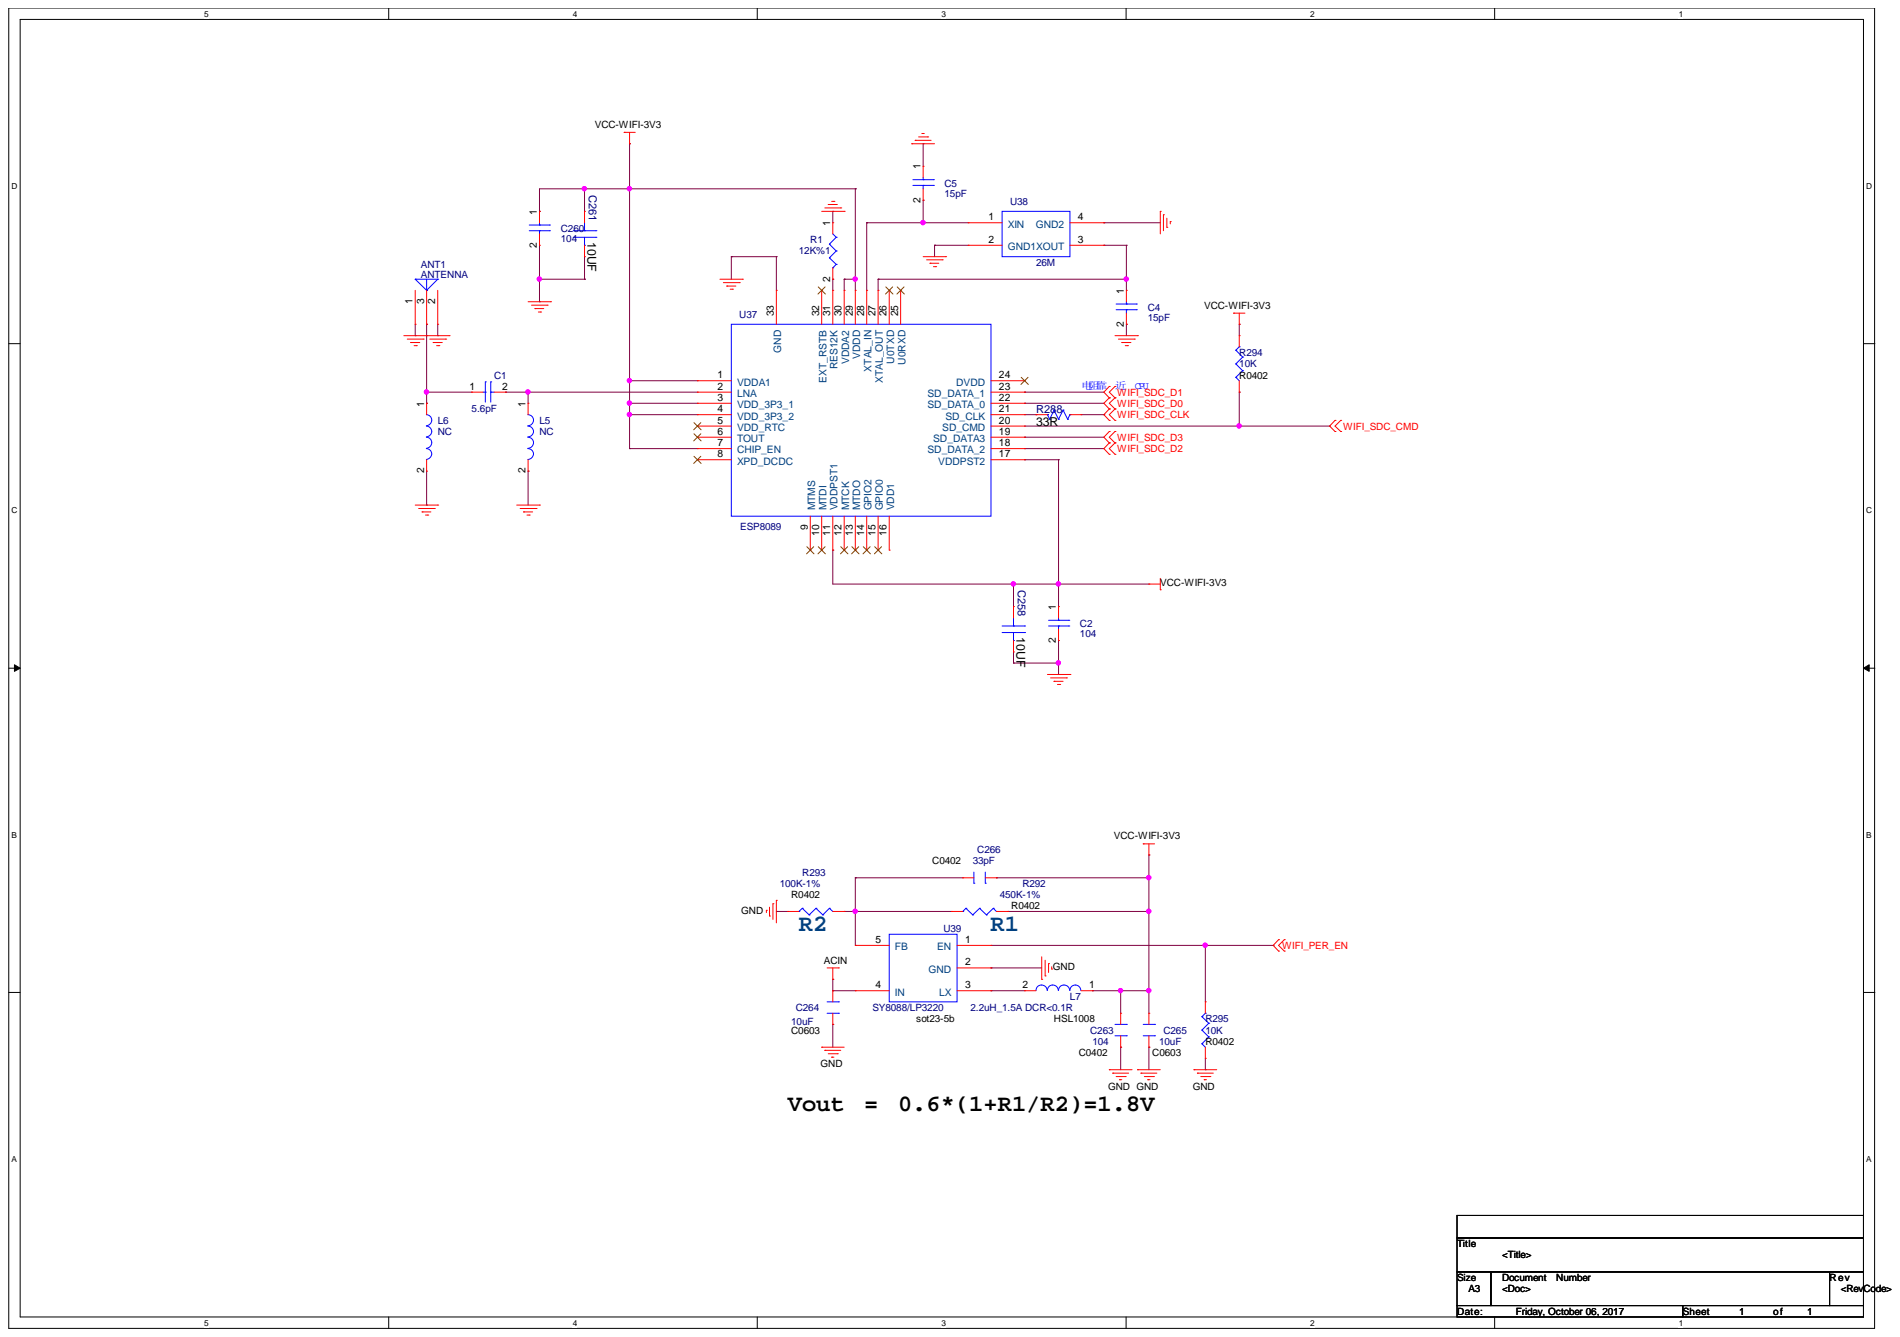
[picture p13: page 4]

# BLOCK DIAGRAM

32.768K | SPI NOR

LRADC0; KEYS; Adapter; AXP203; Battery Voltage Supply 3.55V-4.20V; PMIC; G SENSOR/CTP; TWI1; RGB LCD; RGB; Class D&AB AMP; SPEAKER; CARD0; TF CARD; AUDIO; OSC; MIPI; USB2.0 OTG; MAIN CHIP V3S eLQFP; POWER; 24MHz; DRAMC(DDR2); SPI; DEBUG UART; UART1/UART2; CAMERA; MICROPHONE; Design Name; BLOCK DIAGRAM; V3S_STD_CDR_V1_0; Sunday, October 22, 2017

USB OTG/UVC

AllWinner Technology Co.,Ltd

# POWER TREE

CPU/SYS/EPHY; AVCC/PLL; LDO4; DCDC; LCD BACKLIGHT; DRAM; USB/NOR/TF/FLASH/LED/VCC-IO; RTC/GSENSOR; ACIN; Camera AVDD; LDO; VCC-LCD/PE; 3.3V 30mA ALWAYS-ON; LDO2; LDO1; LDO3; AXP203; USB; BAT; Battery Charger & Power Detect; CAMERA DVDD; SWITCH/DC-DC; UVC; MOS; Camera IOVDD; AUDIO OP

SDC0-D2; SDC0-D0; SDC0-D1; SDC0-CLK; SDC0-D3; TF CARD; PIN; Define; CFGFunction; GPIO; GPIO ASSIGNMENT; SDC0-DET; SPI0_MISO SPI0_CLK SPI0_CS SPI0_MOSI; LCD; LCD_D22; LCD_D20; LCD_D21; TWI0-SDA; LCD_D5; TWI1_SCK; G-SENSOR; LCD_D6; TWI1_SDA; LCD_D7; LCD_D8; LCD_D11; LCD_D12; LCD_D13; LCD_D14; LCD_D15; LCD_D18; LCD_D19; CSI-MIPI-MCLK; 3 MIPI; CSI-SDA; CSI-SCK; LCD_D23; SDC0-CMD; NOR/ NAND; LCD_D3 LCD_D4; LCD_D2; LCD_DE LCD_HSYNC; LCD_CLK; LCD_VSYNC; MIPI-CSI-RESET MIPI-CSI-PWDN; USB-ID PMU-IRQ; PG2 USB-DRVVBUS; CTP-INT; LCD-PWR-EN1; LCD-BL-EN1; PWM0; TWI0-SCK; PA-SHDN; CTP; PMU; AUDIO; CTP-WAKE; Design Name; AllWinner Technology Co.,Ltd; V3S_STD_CDR_V1_0; Friday, October 06, 2017

# CPU

PF


LCD-PWR-EN LCD-D14
VDD-SYS

注： VCC- DRAM/VCC-SYS/VCC-C PU的电容均匀放置于 主控的 各 引 脚。

VCC-USB VCC-MCSI VCC-RTCVCC-PLL

AllWinner Technology Co.,Ltd

# POWER

# LDO1 3.3V


AllWinner Technology Co.,Ltd

# CAMERA

# HEADER 50GND¹ ⁵¹ GND² 52


Near by CPU For EMI

AllWinner Technology Co.,Ltd

# Flash

NOR | CARD0


AllWinner Technology Co.,Ltd

D | D

# AUDIO


Analog Microphone ( Main MIC )

注:D点要靠近耳机 插座， HPC OM、 H P C OM FB分开
走类差分线回 到 主 控。

AllWinner Technology Co.,Ltd

D | D

# USB/WIFI/KEY/GSENSOR


US B-ID 用作 O TG功能ID脚检测， 用来 区别HOST还是

AllWinner Technology Co.,Ltd

USB/WIFI/KEY/GSENSOR

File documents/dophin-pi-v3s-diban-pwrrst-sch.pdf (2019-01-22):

# MISO 8,12 LCD-D11


D1P MIPI-CSI-D1N MIPI-CSI-D0P MIPI-CSI-D0N

CLKP MIPI-CSI-CLKN

BL


LEDA LCD-D19 LCD-D20 LCD-D21 LCD-D22 LCD-D23 LCD-D10 LCD-D11 LCD-D12 LCD-D13 LCD-D14 LCD-D15 LCD-D3 LCD-D4 LCD-D5 LCD-D6 LCD-D7 LCD-CLK LCD-HSYNC LCD-VSYNC


D | D
C | C
B | B
A | A
Schematics | Index：

# P01: REVISION HISTORY P02: BLOCK P03: POWER TREE P04: GPIO ASSIGNMENT P05: CPU P06: POWER P07: CAMERA-MIPI P08: RGB LCD 2.7 P09: NOR NANDFlash/TF Card P10: SPEAKER/MICROPHONE/HEADPHONE P11: USB/KEY/GSENSOR P12: OPTION:RGB LCD 4.3 /CTP/GPS

# REVISION HISTORY

Ver 1.1 | changelist.txt | 2015-08-17 | WJW HW
Revision | Description | Date | Drawn | Checked
Ver 0.1 | Initial | 2015-02-04

Design Name

Size A3 | Page Name REVISION HISTORY REVISION HISTORY REVISION HISTORY | Rev
Date: Monday, August 17, 2015 Monday, August 17, 2015 Monday, August 17, 2015 | Sheet 1 1 1 of 12 12 12

# AllWinner Technology Co.,Ltd

## V3S_STD_CDR_V1_0

Design Name

# AllWinner Technology Co.,Ltd

## V3S_STD_CDR_V1_0

Design Name

# AllWinner Technology Co.,Ltd

## V3S_STD_CDR_V1_0





POWER TREE; CPU/SYS/EPHY; AVCC/PLL; LDO4; DCDC; LCD BACKLIGHT; DRAM; USB/NOR/TF/FLASH/LED/VCC-IO; RTC/GSENSOR; ACIN; Camera AVDD; LDO; VCC-LCD/PE; 3.3V 30mA ALWAYS-ON; LDO2; LDO1; LDO3; AXP203; USB; BAT; Battery Charger & Power Detect; CAMERA DVDD; SWITCH/DC-DC; UVC; MOS; Camera IOVDD; AUDIO OP; Design Name; AllWinner Technology Co.,Ltd; POWER TREE POWER TREE POWER TREE; V3S_STD_CDR_V1_0

Monday, August 17, 2015 Monday, August 17, 2015 Monday, August 17, 2015 | 3 3 3 12 12 12

SDC0-D2; SDC0-D0; SDC0-D1; SDC0-CLK; SDC0-D3; TF CARD; PIN; Define; CFGFunction; GPIO; GPIO ASSIGNMENT; SDC0-DET; SPI0_MISO SPI0_CLK SPI0_CS SPI0_MOSI; LCD; LCD_D22; LCD_D20; LCD_D21; TWI0-SDA; LCD_D5; TWI1_SCK; G-SENSOR; LCD_D6; TWI1_SDA; LCD_D7; LCD_D8; LCD_D11; LCD_D12; LCD_D13; LCD_D14; LCD_D15; LCD_D18; LCD_D19; CSI-MIPI-MCLK; 3 MIPI; CSI-SDA; CSI-SCK; LCD_D23; SDC0-CMD; NOR/ NAND; LCD_D3 LCD_D4; LCD_D2; LCD_DE LCD_HSYNC; LCD_CLK; LCD_VSYNC; MIPI-CSI-RESET MIPI-CSI-PWDN; USB-ID PMU-IRQ; PG2 USB-DRVVBUS; CTP-INT; LCD-PWR-EN1; LCD-BL-EN1; PWM0; TWI0-SCK; PA-SHDN; CTP; PMU; AUDIO; CTP-WAKE; Design Name; AllWinner Technology Co.,Ltd; V3S_STD_CDR_V1_0; Monday, May 18, 2015

# CAMERA

3V3


Near by CPU For EMI

AllWinner Technology Co.,Ltd

CARD0; SD CARD; TF-VDD; GND; VCC-DEVICE; SDC0-D2; SDC0-CMD; SDC0-D3; SDC0-CLK; SDC0-D0; SDC0-D1; SDC0-DET; Design Name; MEMORY; V3S_STD_CDR_V1_0; Tuesday, March 06, 2018; DAT2; CD/DAT3; CMD; VDD; 4 CLK 5 VSS 6; DAT0; DAT1; 8 GND1 9 GND2 10 POL 11; DET; 12 GND3 13

AllWinner Technology Co.,Ltd

D | D

# AUDIO


Analog Microphone ( Main MIC )

注:D点要靠近耳机 插座， HPC OM、 H P C OM FB分开
走类差分线回 到 主 控。

AllWinner Technology Co.,Ltd

D | D

# USB/WIFI/KEY/GSENSOR

KEY; DEVICE 接入; ; 倒车检测 功能在USB摄 像头上实现 ，通过USB 上 报。; 注：每隔 0.2V一个按键; 注： 预留作为 PCBA烧录 时使 用， 整机不能有 该 按键 ; 整机升级需使用组 合键。; KEY-VOL+; KEY-VOL-; USB-DP USB-DM; GND; AVCC; VCC_5V; ACIN; VCC_SYS; VCC50_IN; KEYADC0; USB-DM; USB-DP; SPI-MISO; RESET; Design Name; V3S_STD_CDR_V1_0; Sunday, May 20, 2018; S3 VOL+; S4 VOL-; S2 FEL; MICROUSB; VBUS 1; 4 GND5 5; GND4 6 GND3 7 GND2 8 GND1 9; S5 FEL

US B-ID 用作 O TG功能ID脚检测， 用来 区别HOST还是

USB OTG/UVC

USB-DM
USB-DP
USB-ID-JIN

AllWinner Technology Co.,Ltd

USB/WIFI/KEY/GSENSOR

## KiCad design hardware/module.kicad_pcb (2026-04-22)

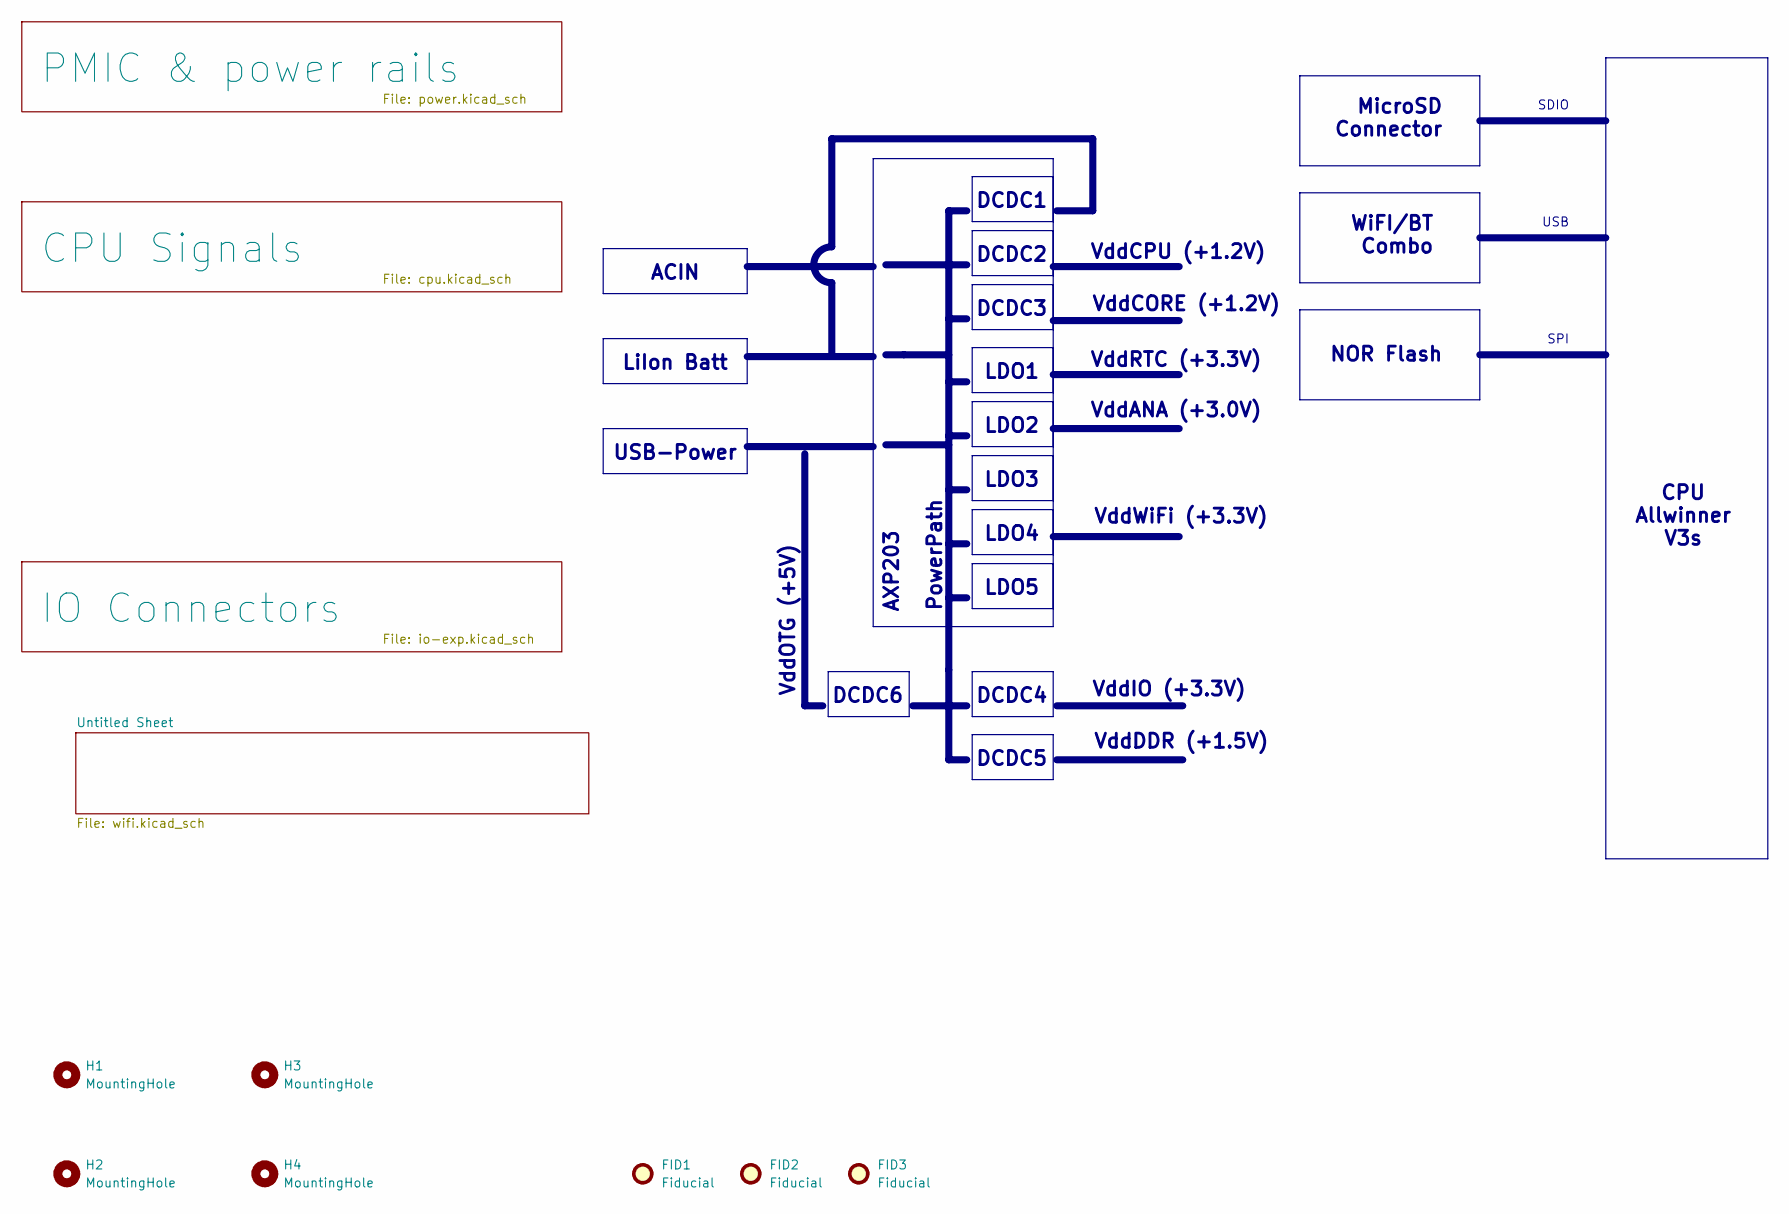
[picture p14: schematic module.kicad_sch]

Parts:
FID1, FID2, FID3: Fiducial; Fiducial_0.75mm_Mask1.5mm
H1, H2, H3, H4: MountingHole; MountingHole_2.7mm_M2.5_DIN965

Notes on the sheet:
LDO1
LDO5
VddWiFi (+3.3V)
CPU Allwinner V3s
DCDC3
SPI
DCDC6
VddOTG (+5V)
WiFI/BT Combo
DCDC4
LDO4
VddCPU (+1.2V)
VddANA (+3.0V)
VddCORE (+1.2V)
SDIO
USB
DCDC1
LDO3
DCDC5
ACIN
LDO2
LiIon Batt
VddRTC (+3.3V)
USB-Power
AXP203
DCDC2
MicroSD Connector
NOR Flash
VddIO (+3.3V)
PowerPath
VddDDR (+1.5V)

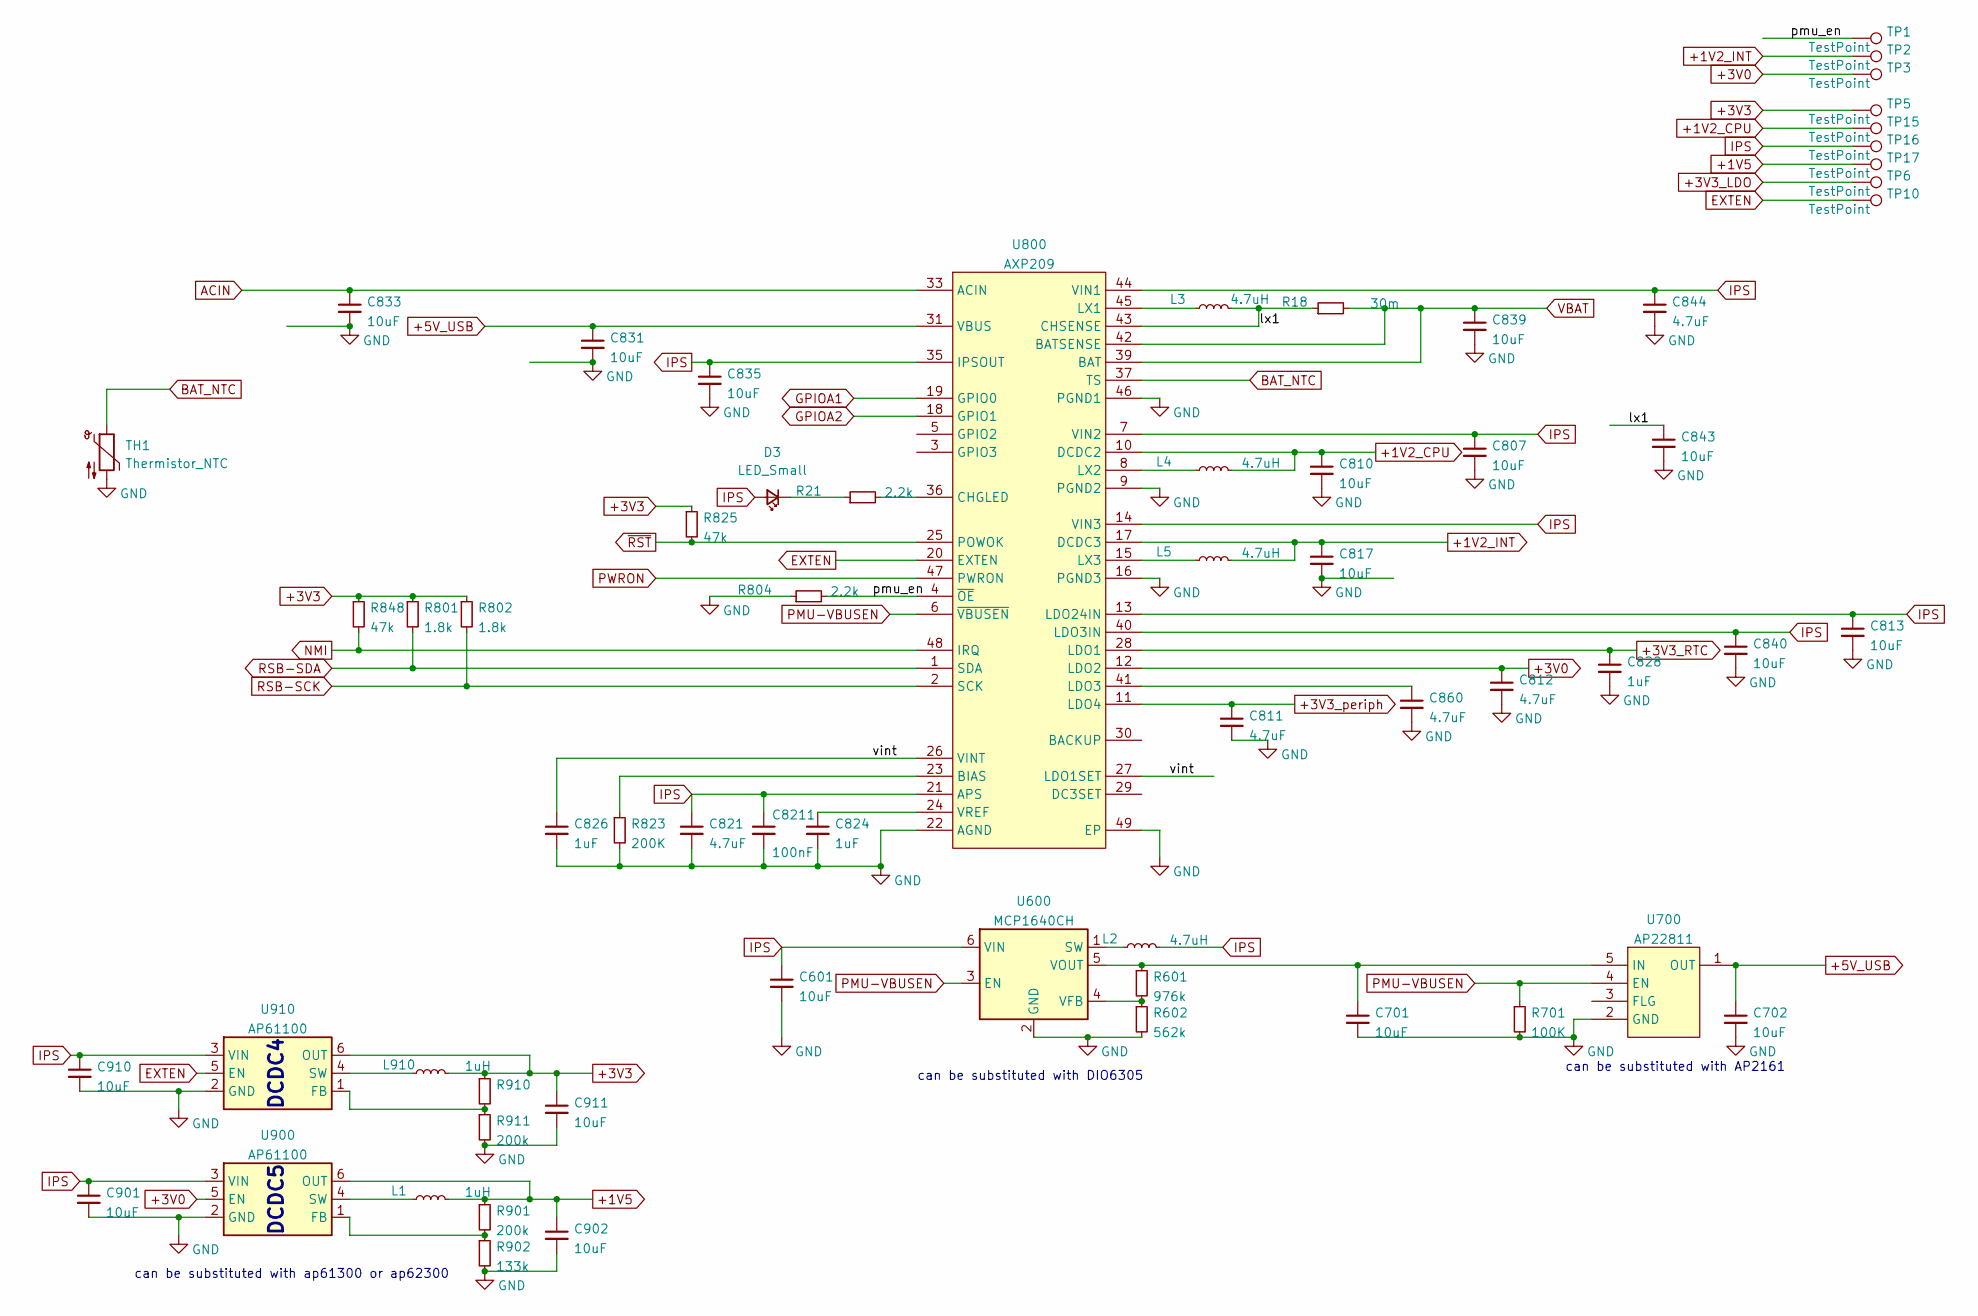
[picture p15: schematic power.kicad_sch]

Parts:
C601, C701, C702, C807, C810, C813, C817, C831, C833, C835, C839, C840, C843, C901, C902, C910, C911: 10uF; C_0603_1608Metric
C811, C812, C821, C844, C860: 4.7uF; C_0603_1608Metric
C824, C826, C828: 1uF; C_0402_1005Metric
C8211: 100nF; C_0402_1005Metric
D3: LED_Small; LED_0603_1608Metric
L1, L910: 1uH; L_Wuerth_MAPI-2510
L2: 4.7uH; L_Wuerth_MAPI-2510
L3, L4, L5: 4.7uH; L_Wuerth_MAPI-2512
R18: 30m; R_0603_1608Metric
R21, R804: 2.2k; R_0402_1005Metric
R601: 976k; R_0402_1005Metric
R602: 562k; R_0402_1005Metric
R701: 100K; R_0402_1005Metric
R801, R802: 1.8k; R_0402_1005Metric
R823: 200K; R_0402_1005Metric
R825, R848: 47k; R_0402_1005Metric
R901, R911: 200k; R_0402_1005Metric
R902: 133k; R_0402_1005Metric
R910: R_0402_1005Metric
TH1: Thermistor_NTC; R_0603_1608Metric
TP1, TP2, TP3, TP5, TP6, TP10, TP15, TP16, TP17: TestPoint; TestPoint_Pad_D1.0mm
U600: MCP1640CH; SOT-23-6
U700: AP22811; SOT-23-5
U800: AXP209; QFN-48-1EP_6x6mm_P0.4mm_EP4.2x4.2mm_ThermalVias
U900, U910: AP61100; SOT-563

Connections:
+1V2_CPU: C810.1, L4.2, TP15.1, U800.10 (DCDC2)
+1V2_INT: C817.1, L5.2, TP2.1, U800.17 (DCDC3)
+1V5: C902.1, L1.2, R901.1, TP17.1, U900.6 (OUT)
+3V0: C812.1, TP3.1, U800.12 (LDO2), U900.5 (EN); also elsewhere on the board
+3V3: C911.1, L910.2, R801.1, R802.1, R825.1, R848.1, R910.1, TP5.1, U910.6 (OUT); also elsewhere on the board
+3V3_LDO: TP6.1; also elsewhere on the board
+3V3_RTC: C828.1, U800.28 (LDO1); also elsewhere on the board
+3V3_periph: C811.1, U800.11 (LDO4)
+5V_USB: C702.1, C831.1, U700.1 (OUT), U800.31 (VBUS); also elsewhere on the board
/PMIC & power rails/lx1: C843.1, L3.2, R18.1, U800.43 (CHSENSE)
/PMIC & power rails/pmu_en: R804.2, TP1.1, U800.4 (~OE)
/PMIC & power rails/vint: C826.1, U800.26 (VINT), U800.27 (LDO1SET)
ACIN: C833.1, U800.32 (ACIN), U800.33 (ACIN); also elsewhere on the board
BAT_NTC: TH1.1, U800.37 (TS); also elsewhere on the board
EXTEN: TP10.1, U800.20 (EXTEN), U910.5 (EN)
GND: C601.2, C701.2, C702.2, C807.2, C810.2, C811.2, C812.2, C813.2, C817.2, C821.2, C824.2, C826.2, C828.2, C831.2, C833.2, C835.2, C839.2, C840.2, C843.2, C844.2, C860.2, C901.2, C902.2, C910.2, C911.2, C8211.2, R602.2, R701.2, R804.1, R823.2, R902.2, R911.2, TH1.2, U600.2 (GND), U700.2 (GND), U800.9 (PGND2), U800.16 (PGND3), U800.22 (AGND), U800.46 (PGND1), U800.49 (EP), U900.2 (GND), U910.2 (GND); also elsewhere on the board
GPIOA1: U800.19 (GPIO0); also elsewhere on the board
GPIOA2: U800.18 (GPIO1); also elsewhere on the board
IPS: C601.1, C807.1, C813.1, C821.1, C835.1, C840.1, C844.1, C901.1, C910.1, C8211.1, D3.2 (A), L2.2, TP16.1, U600.6 (VIN), U800.7 (VIN2), U800.13 (LDO24IN), U800.14 (VIN3), U800.21 (APS), U800.34 (IPSOUT), U800.35 (IPSOUT), U800.40 (LDO3IN), U800.44 (VIN1), U900.3 (VIN), U910.3 (VIN)
NMI: R848.2, U800.48 (IRQ); also elsewhere on the board
unnamed: D3.1 (K), R21.1
unnamed: L2.1, U600.1 (SW)
unnamed: R601.2, R602.1, U600.4 (VFB)
unnamed: C701.1, R601.1, U600.5 (VOUT), U700.5 (IN)
unnamed: R823.1, U800.23 (BIAS)
unnamed: R21.2, U800.36 (CHGLED)
unnamed: C860.1, U800.41 (LDO3)
unnamed: L3.1, U800.45 (LX1)
unnamed: L4.1, U800.8 (LX2)
unnamed: L5.1, U800.15 (LX3)
unnamed: C824.1, U800.24 (VREF)
unnamed: R901.2, R902.1, U900.1 (FB)
unnamed: L1.1, U900.4 (SW)
unnamed: R910.2, R911.1, U910.1 (FB)
unnamed: L910.1, U910.4 (SW)
PMU-VBUSEN: R701.1, U600.3 (EN), U700.4 (EN), U800.6 (~VBUSEN); also elsewhere on the board
PWRON: U800.47 (PWRON); also elsewhere on the board
RSB-SCK: R802.2, U800.2 (SCK); also elsewhere on the board
RSB-SDA: R801.2, U800.1 (SDA); also elsewhere on the board
VBAT: C839.1, R18.2, U800.38 (BAT), U800.39 (BAT), U800.42 (BATSENSE); also elsewhere on the board
~RST: R825.2, U800.25 (POWOK); also elsewhere on the board

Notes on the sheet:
DCDC5
can be substituted with ap61300 or ap62300
can be substituted with DIO6305
DCDC4
can be substituted with AP2161

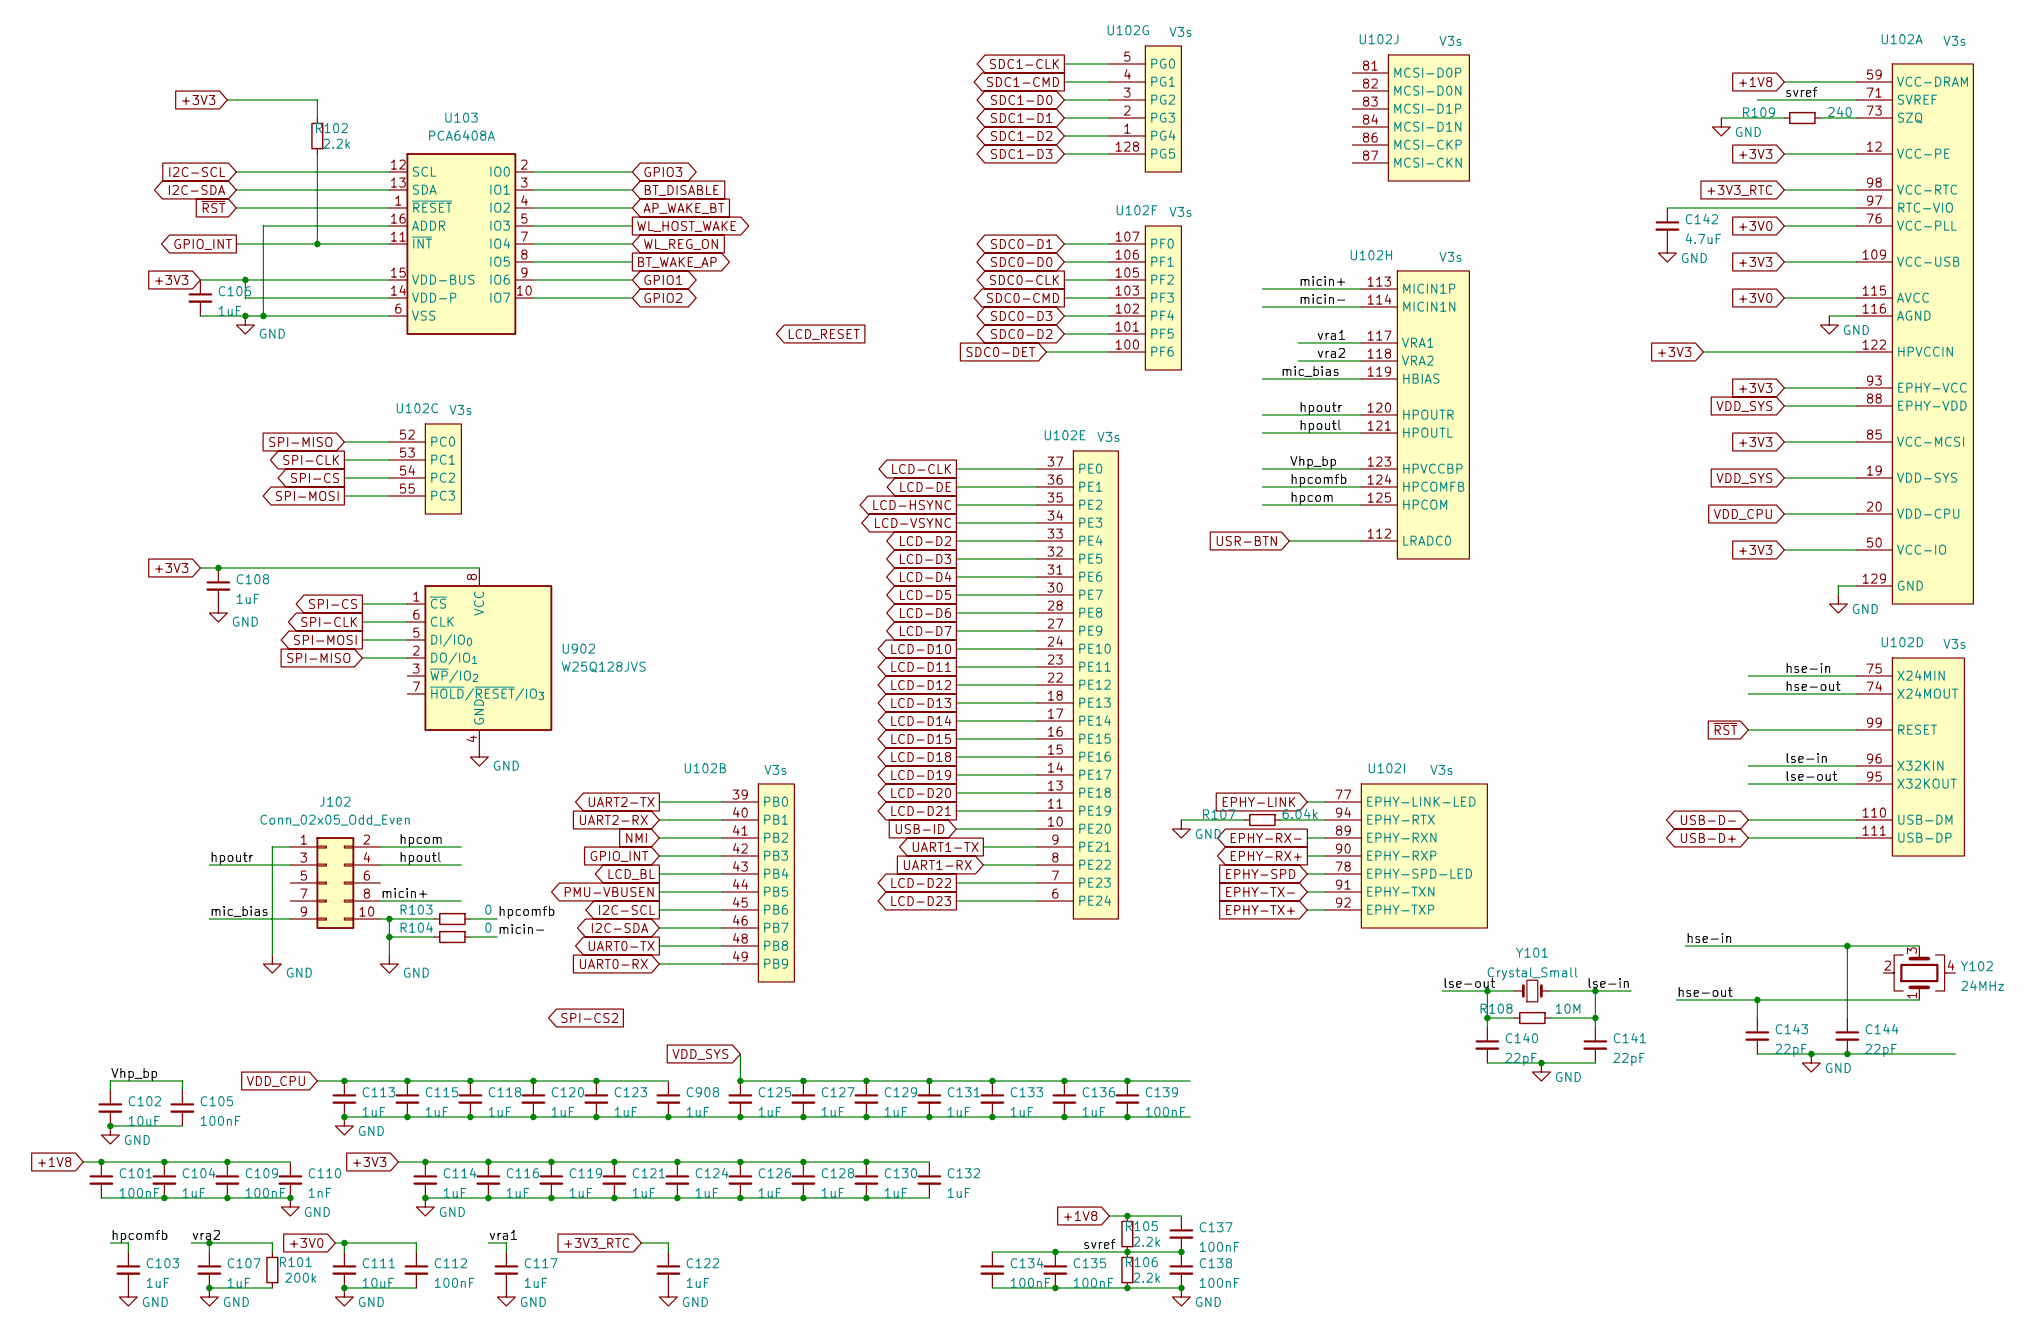
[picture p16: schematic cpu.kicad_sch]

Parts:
C101, C105, C109, C112, C134, C135, C137, C138, C139: 100nF; C_0402_1005Metric
C102, C111: 10uF; C_0603_1608Metric
C103, C104, C106, C107, C108, C113, C114, C115, C116, C117, C118, C119, C120, C121, C122, C123, C124, C125, C126, C127, C128, C129, C130, C131, C132, C133, C136, C908: 1uF; C_0402_1005Metric
C110: 1nF; C_0402_1005Metric
C140, C141, C143, C144: 22pF; C_0402_1005Metric
C142: 4.7uF; C_0402_1005Metric
J102: Conn_02x05_Odd_Even; PinHeader_2x05_P1.27mm_Vertical
R101: 200k; R_0402_1005Metric
R102, R105, R106: 2.2k; R_0402_1005Metric
R103, R104: 0; R_0402_1005Metric
R107: 6.04k; R_0402_1005Metric
R108: 10M; R_0402_1005Metric
R109: 240; R_0402_1005Metric
U102: V3s; QFP-128_14x14_Pitch0.4mm
U103: PCA6408A; QFN-16-1EP_3x3mm_P0.5mm_EP1.7x1.7mm
U902: W25Q128JVS; SOIC-8_5.3x5.3mm_P1.27mm
Y101: Crystal_Small; Crystal_SMD_3215-2Pin_3.2x1.5mm
Y102: 24MHz; Crystal_SMD_3225-4Pin_3.2x2.5mm

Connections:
+1V8: C101.1, C104.1, C109.1, C110.1, C137.1, R105.2, U102.59 (VCC-DRAM), U102.60 (VCC-DRAM), U102.61 (VCC-DRAM), U102.62 (VCC-DRAM), U102.65 (VCC-DRAM), U102.66 (VCC-DRAM), U102.67 (VCC-DRAM), U102.68 (VCC-DRAM), U102.69 (VCC-DRAM), U102.70 (VCC-DRAM), U102.72 (VCC-DRAM), U102.79 (VCC-DRAM)
+3V0: C111.1, C112.1, U102.76 (VCC-PLL), U102.115 (AVCC); also elsewhere on the board
+3V3: C106.1, C108.1, C114.1, C116.1, C119.1, C121.1, C124.1, C126.1, C128.1, C130.1, C132.1, R102.2, U102.12 (VCC-PE), U102.29 (VCC-PE), U102.50 (VCC-IO), U102.57 (VCC-IO), U102.85 (VCC-MCSI), U102.93 (EPHY-VCC), U102.104 (VCC-IO), U102.109 (VCC-USB), U102.122 (HPVCCIN), U102.127 (VCC-IO), U103.14 (VDD-P), U103.15 (VDD-BUS), U902.8 (VCC); also elsewhere on the board
+3V3_RTC: C122.1, U102.98 (VCC-RTC); also elsewhere on the board
/CPU Signals/Vhp_bp: C102.1, C105.1, U102.123 (HPVCCBP)
/CPU Signals/hpcom: J102.2, U102.125 (HPCOM)
/CPU Signals/hpcomfb: C103.1, R103.1, U102.124 (HPCOMFB)
/CPU Signals/hpoutl: J102.4, U102.121 (HPOUTL)
/CPU Signals/hpoutr: J102.3, U102.120 (HPOUTR)
/CPU Signals/hse-in: C144.1, U102.75 (X24MIN), Y102.3
/CPU Signals/hse-out: C143.1, U102.74 (X24MOUT), Y102.1
/CPU Signals/lse-in: C141.1, R108.1, U102.96 (X32KIN), Y101.2
/CPU Signals/lse-out: C140.1, R108.2, U102.95 (X32KOUT), Y101.1
/CPU Signals/mic_bias: J102.9, U102.119 (HBIAS)
/CPU Signals/micin+: J102.8, U102.113 (MICIN1P)
/CPU Signals/micin-: R104.1, U102.114 (MICIN1N)
/CPU Signals/svref: C134.1, C135.1, C137.2, C138.1, R105.1, R106.2, U102.63 (SVREF), U102.71 (SVREF)
/CPU Signals/vra1: C117.1, U102.117 (VRA1)
/CPU Signals/vra2: C107.1, R101.2, U102.118 (VRA2)
AP_WAKE_BT: U103.4 (IO2); also elsewhere on the board
BT_DISABLE: U103.3 (IO1); also elsewhere on the board
BT_WAKE_AP: U103.8 (IO5); also elsewhere on the board
EPHY-LINK: U102.77 (EPHY-LINK-LED); also elsewhere on the board
EPHY-RX+: U102.90 (EPHY-RXP); also elsewhere on the board
EPHY-RX-: U102.89 (EPHY-RXN); also elsewhere on the board
EPHY-SPD: U102.78 (EPHY-SPD-LED); also elsewhere on the board
EPHY-TX+: U102.92 (EPHY-TXP); also elsewhere on the board
EPHY-TX-: U102.91 (EPHY-TXN); also elsewhere on the board
GND: C101.2, C102.2, C103.2, C104.2, C105.2, C106.2, C107.2, C108.2, C109.2, C110.2, C111.2, C112.2, C113.2, C114.2, C115.2, C116.2, C117.2, C118.2, C119.2, C120.2, C121.2, C122.2, C123.2, C124.2, C125.2, C126.2, C127.2, C128.2, C129.2, C130.2, C131.2, C132.2, C133.2, C134.2, C135.2, C136.2, C138.2, C139.2, C140.2, C141.2, C142.2, C143.2, C144.2, C908.2, J102.1, J102.10, R101.1, R103.2, R104.2, R106.1, R107.2, R109.2, U102.116 (AGND), U102.129 (GND), U103.6 (VSS), U103.16 (ADDR), U902.4 (GND); also elsewhere on the board
GPIO1: U103.9 (IO6); also elsewhere on the board
GPIO2: U103.10 (IO7); also elsewhere on the board
GPIO3: U103.2 (IO0); also elsewhere on the board
GPIO_INT: R102.1, U102.42 (PB3), U103.11 (~INT)
I2C-SCL: U102.45 (PB6), U103.12 (SCL); also elsewhere on the board
I2C-SDA: U102.46 (PB7), U103.13 (SDA); also elsewhere on the board
LCD-CLK: U102.37 (PE0); also elsewhere on the board
LCD-D2: U102.33 (PE4); also elsewhere on the board
LCD-D3: U102.32 (PE5); also elsewhere on the board
LCD-D4: U102.31 (PE6); also elsewhere on the board
LCD-D5: U102.30 (PE7); also elsewhere on the board
LCD-D6: U102.28 (PE8); also elsewhere on the board
LCD-D7: U102.27 (PE9); also elsewhere on the board
LCD-D10: U102.24 (PE10); also elsewhere on the board
LCD-D11: U102.23 (PE11); also elsewhere on the board
LCD-D12: U102.22 (PE12); also elsewhere on the board
LCD-D13: U102.18 (PE13); also elsewhere on the board
LCD-D14: U102.17 (PE14); also elsewhere on the board
LCD-D15: U102.16 (PE15); also elsewhere on the board
LCD-D18: U102.15 (PE16); also elsewhere on the board
LCD-D19: U102.14 (PE17); also elsewhere on the board
LCD-D20: U102.13 (PE18); also elsewhere on the board
LCD-D21: U102.11 (PE19); also elsewhere on the board
LCD-D22: U102.7 (PE23); also elsewhere on the board
LCD-D23: U102.6 (PE24); also elsewhere on the board
LCD-DE: U102.36 (PE1); also elsewhere on the board
LCD-HSYNC: U102.35 (PE2); also elsewhere on the board
LCD-VSYNC: U102.34 (PE3); also elsewhere on the board
LCD_BL: U102.43 (PB4); also elsewhere on the board
NMI: U102.41 (PB2); also elsewhere on the board
unnamed: C142.1, U102.97 (RTC-VIO)
unnamed: R109.1, U102.73 (SZQ)
unnamed: R107.1, U102.94 (EPHY-RTX)
PMU-VBUSEN: U102.44 (PB5); also elsewhere on the board
SDC0-CLK: U102.105 (PF2); also elsewhere on the board
SDC0-CMD: U102.103 (PF3); also elsewhere on the board
SDC0-D0: U102.106 (PF1); also elsewhere on the board
SDC0-D1: U102.107 (PF0); also elsewhere on the board
SDC0-D2: U102.101 (PF5); also elsewhere on the board
SDC0-D3: U102.102 (PF4); also elsewhere on the board
SDC0-DET: U102.100 (PF6); also elsewhere on the board
SDC1-CLK: U102.5 (PG0); also elsewhere on the board
SDC1-CMD: U102.4 (PG1); also elsewhere on the board
SDC1-D0: U102.3 (PG2); also elsewhere on the board
SDC1-D1: U102.2 (PG3); also elsewhere on the board
SDC1-D2: U102.1 (PG4); also elsewhere on the board
SDC1-D3: U102.128 (PG5); also elsewhere on the board
SPI-CLK: U102.53 (PC1), U902.6 (CLK); also elsewhere on the board
SPI-CS: U102.54 (PC2), U902.1 (~CS)
SPI-MISO: U102.52 (PC0), U902.2 (DO/IO_{1}); also elsewhere on the board
SPI-MOSI: U102.55 (PC3), U902.5 (DI/IO_{0}); also elsewhere on the board
UART0-RX: U102.49 (PB9)
UART0-TX: U102.48 (PB8)
UART1-RX: U102.8 (PE22); also elsewhere on the board
UART1-TX: U102.9 (PE21); also elsewhere on the board
UART2-RX: U102.40 (PB1); also elsewhere on the board
UART2-TX: U102.39 (PB0); also elsewhere on the board
USB-D+: U102.111 (USB-DP)
USB-D-: U102.110 (USB-DM)
USB-ID: U102.10 (PE20)
USR-BTN: U102.112 (LRADC0)
VDD_CPU: C113.1, C115.1, C118.1, C120.1, C123.1, C908.1, U102.20 (VDD-CPU), U102.21 (VDD-CPU), U102.25 (VDD-CPU), U102.26 (VDD-CPU), U102.38 (VDD-CPU), U102.47 (VDD-CPU), U102.51 (VDD-CPU), U102.56 (VDD-CPU)
VDD_SYS: C125.1, C127.1, C129.1, C131.1, C133.1, C136.1, C139.1, U102.19 (VDD-SYS), U102.58 (VDD-SYS), U102.64 (VDD-SYS), U102.80 (VDD-SYS), U102.88 (EPHY-VDD), U102.108 (VDD-SYS), U102.126 (VDD-SYS)
WL_HOST_WAKE: U103.5 (IO3); also elsewhere on the board
WL_REG_ON: U103.7 (IO4); also elsewhere on the board
~RST: U102.99 (RESET), U103.1 (~RESET); also elsewhere on the board

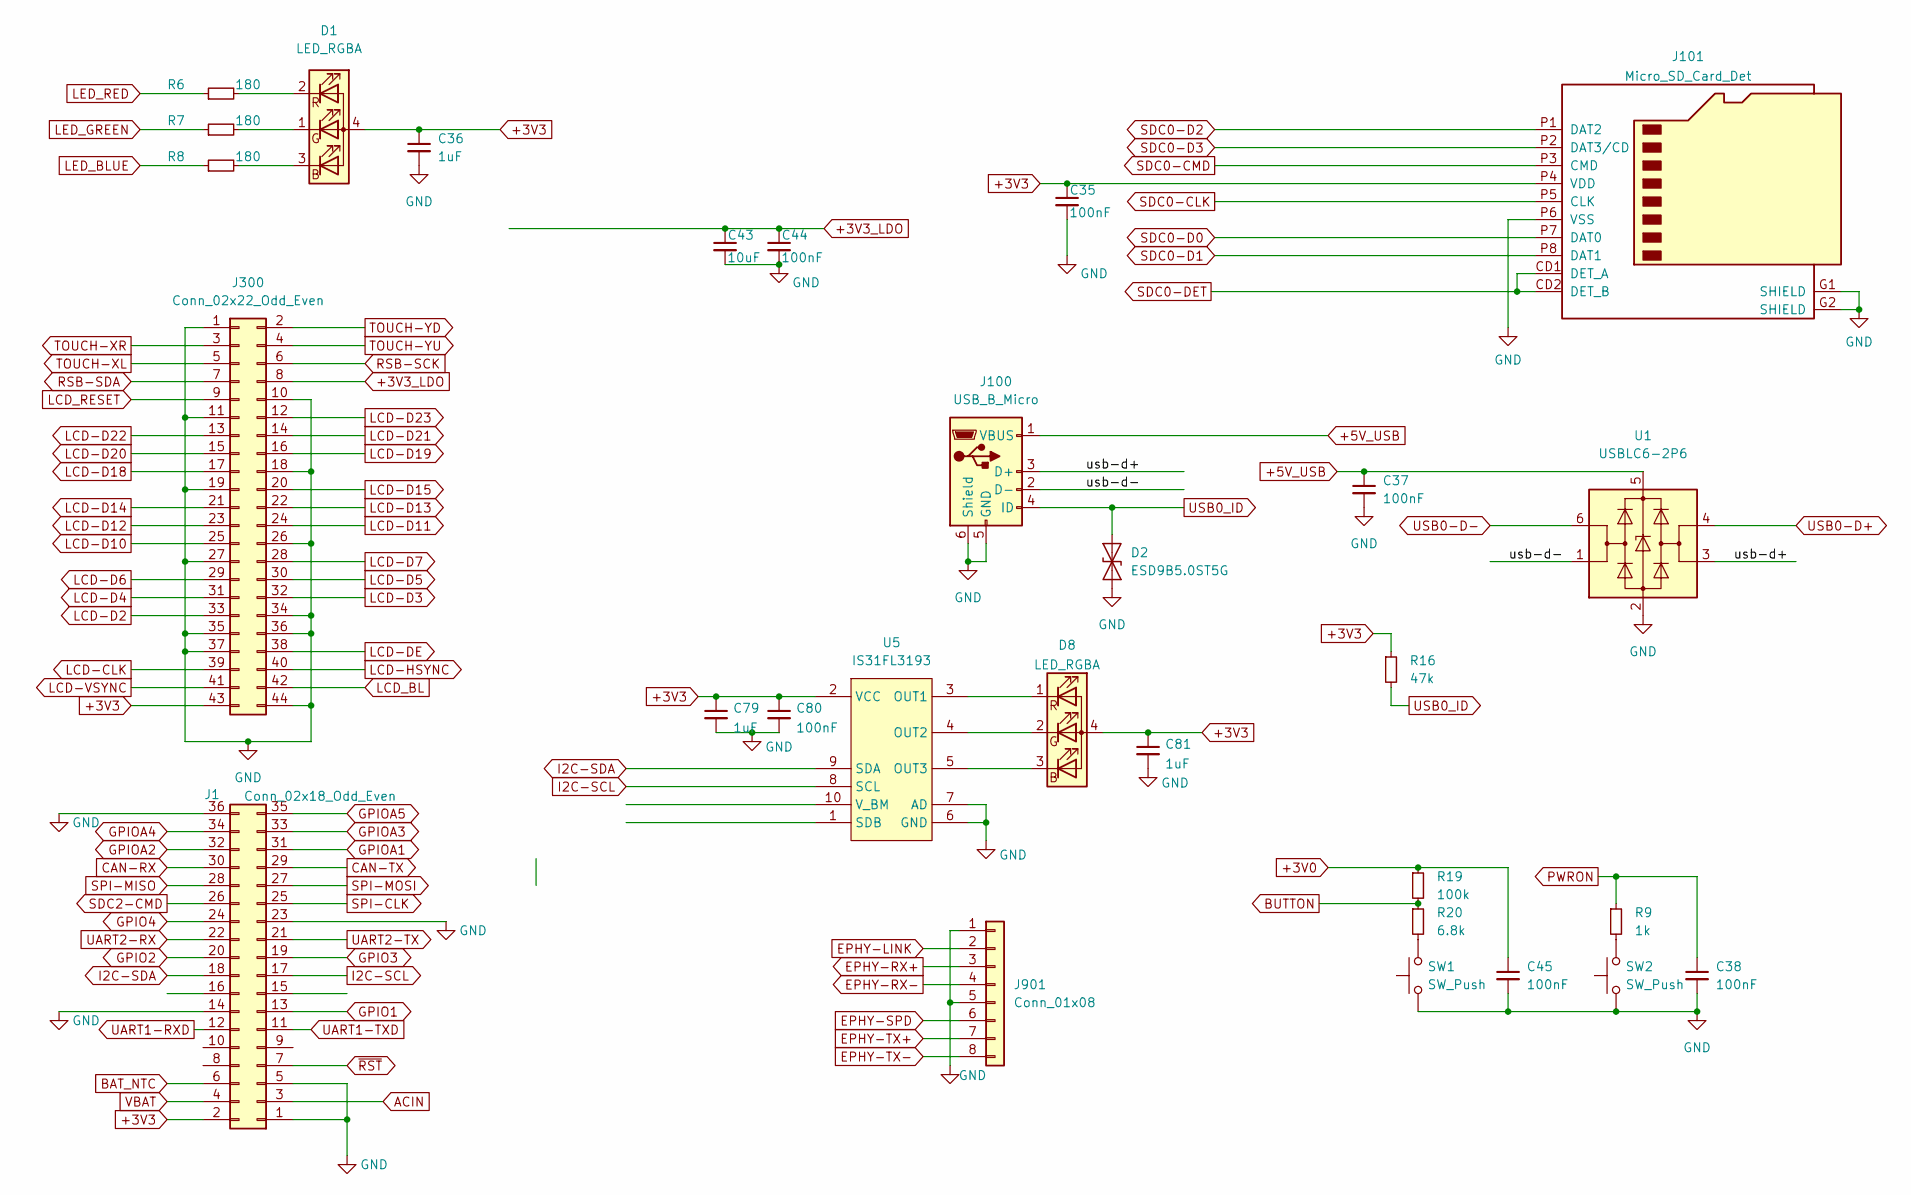
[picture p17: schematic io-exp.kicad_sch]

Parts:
C35: 100nF; C_0603_1608Metric
C36, C79, C81: 1uF; C_0402_1005Metric
C37, C38, C44, C45, C80: 100nF; C_0402_1005Metric
C43: 10uF; C_0603_1608Metric
D1, D8: LED_RGBA; rgb-1204
D2: ESD9B5.0ST5G; D_SOD-923
J1: Conn_02x18_Odd_Even; PinHeader_2x18_P2.54mm_Vertical
J100: USB_B_Micro; USB_Micro-B_Amphenol_10103594-0001LF_Horizontal
J101: Micro_SD_Card_Det; MEM20610118800A
J300: Conn_02x22_Odd_Even; PinHeader_2x22_P1.27mm_Vertical
J901: Conn_01x08; PinSocket_2x04_P1.27mm_Vertical
R6, R7, R8: 180; R_0402_1005Metric
R9: 1k; R_0402_1005Metric
R16: 47k; R_0402_1005Metric
R19: 100k; R_0402_1005Metric
R20: 6.8k; R_0402_1005Metric
SW1, SW2: SW_Push; SW_SPST_EVQP7C
U1: USBLC6-2P6; SOT-23-6
U5: IS31FL3193; DFN-10-1EP_3x3mm_P0.5mm_EP1.7x2.5mm

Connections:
+3V0: C45.1, R19.1; also elsewhere on the board
+3V3: C35.1, C36.1, C79.1, C80.1, C81.1, D1.4 (A), D8.4 (A), J1.2, J101.P4 (VDD), J300.43, R16.1, U5.2 (VCC); also elsewhere on the board
+3V3_LDO: C43.1, C44.1, J300.8; also elsewhere on the board
+5V_USB: C37.1, J100.1 (VBUS), U1.5 (VBUS); also elsewhere on the board
/IO Connectors/usb-d+: J100.3 (D+), U1.3 (I/O2)
/IO Connectors/usb-d-: J100.2 (D-), U1.1 (I/O1)
ACIN: J1.3; also elsewhere on the board
BAT_NTC: J1.6; also elsewhere on the board
BUTTON: R19.2, R20.1
CAN-RX: J1.30
CAN-TX: J1.29
EPHY-LINK: J901.2; also elsewhere on the board
EPHY-RX+: J901.3; also elsewhere on the board
EPHY-RX-: J901.4; also elsewhere on the board
EPHY-SPD: J901.6; also elsewhere on the board
EPHY-TX+: J901.7; also elsewhere on the board
EPHY-TX-: J901.8; also elsewhere on the board
GND: C35.2, C36.2, C37.2, C38.2, C43.2, C44.2, C45.2, C79.2, C80.2, C81.2, D2.2 (A2), J1.1, J1.5, J1.14, J1.23, J1.36, J100.5 (GND), J100.6 (Shield), J101.G1 (SHIELD), J101.G2 (SHIELD), J101.P6 (VSS), J300.1, J300.10, J300.11, J300.18, J300.19, J300.26, J300.27, J300.34, J300.35, J300.36, J300.37, J300.44, J901.1, J901.5, SW1.1, SW2.1, U1.2 (GND), U5.6 (GND), U5.7 (AD), U5.11 (GND); also elsewhere on the board
GPIO1: J1.13; also elsewhere on the board
GPIO2: J1.20; also elsewhere on the board
GPIO3: J1.19; also elsewhere on the board
GPIO4: J1.24
GPIOA1: J1.31; also elsewhere on the board
GPIOA2: J1.32; also elsewhere on the board
GPIOA3: J1.33
GPIOA4: J1.34
GPIOA5: J1.35
I2C-SCL: J1.17, U5.8 (SCL); also elsewhere on the board
I2C-SDA: J1.18, U5.9 (SDA); also elsewhere on the board
LCD-CLK: J300.39; also elsewhere on the board
LCD-D2: J300.33; also elsewhere on the board
LCD-D3: J300.32; also elsewhere on the board
LCD-D4: J300.31; also elsewhere on the board
LCD-D5: J300.30; also elsewhere on the board
LCD-D6: J300.29; also elsewhere on the board
LCD-D7: J300.28; also elsewhere on the board
LCD-D10: J300.25; also elsewhere on the board
LCD-D11: J300.24; also elsewhere on the board
LCD-D12: J300.23; also elsewhere on the board
LCD-D13: J300.22; also elsewhere on the board
LCD-D14: J300.21; also elsewhere on the board
LCD-D15: J300.20; also elsewhere on the board
LCD-D18: J300.17; also elsewhere on the board
LCD-D19: J300.16; also elsewhere on the board
LCD-D20: J300.15; also elsewhere on the board
LCD-D21: J300.14; also elsewhere on the board
LCD-D22: J300.13; also elsewhere on the board
LCD-D23: J300.12; also elsewhere on the board
LCD-DE: J300.38; also elsewhere on the board
LCD-HSYNC: J300.40; also elsewhere on the board
LCD-VSYNC: J300.41; also elsewhere on the board
LCD_BL: J300.42; also elsewhere on the board
LCD_RESET: J300.9
LED_BLUE: R8.1
LED_GREEN: R7.1
LED_RED: R6.1
unnamed: D1.3 (BK), R8.2
unnamed: D1.1 (GK), R7.2
unnamed: D1.2 (RK), R6.2
unnamed: D8.3 (BK), U5.5 (OUT3)
unnamed: D8.2 (GK), U5.4 (OUT2)
unnamed: D8.1 (RK), U5.3 (OUT1)
unnamed: R9.2, SW2.2
unnamed: R20.2, SW1.2
PWRON: C38.1, R9.1; also elsewhere on the board
RSB-SCK: J300.6; also elsewhere on the board
RSB-SDA: J300.7; also elsewhere on the board
SDC0-CLK: J101.P5 (CLK); also elsewhere on the board
SDC0-CMD: J101.P3 (CMD); also elsewhere on the board
SDC0-D0: J101.P7 (DAT0); also elsewhere on the board
SDC0-D1: J101.P8 (DAT1); also elsewhere on the board
SDC0-D2: J101.P1 (DAT2); also elsewhere on the board
SDC0-D3: J101.P2 (DAT3/CD); also elsewhere on the board
SDC0-DET: J101.CD1 (DET_A), J101.CD2 (DET_B); also elsewhere on the board
SDC2-CMD: J1.26
SPI-CLK: J1.25; also elsewhere on the board
SPI-MISO: J1.28; also elsewhere on the board
SPI-MOSI: J1.27; also elsewhere on the board
TOUCH-XL: J300.5
TOUCH-XR: J300.3
TOUCH-YD: J300.2
TOUCH-YU: J300.4
UART1-RXD: J1.12
UART1-TXD: J1.11
UART2-RX: J1.22; also elsewhere on the board
UART2-TX: J1.21; also elsewhere on the board
USB0-D+: U1.4 (I/O2)
USB0-D-: U1.6 (I/O1)
USB0_ID: D2.1 (A1), J100.4 (ID), R16.2
VBAT: J1.4; also elsewhere on the board
~RST: J1.7; also elsewhere on the board

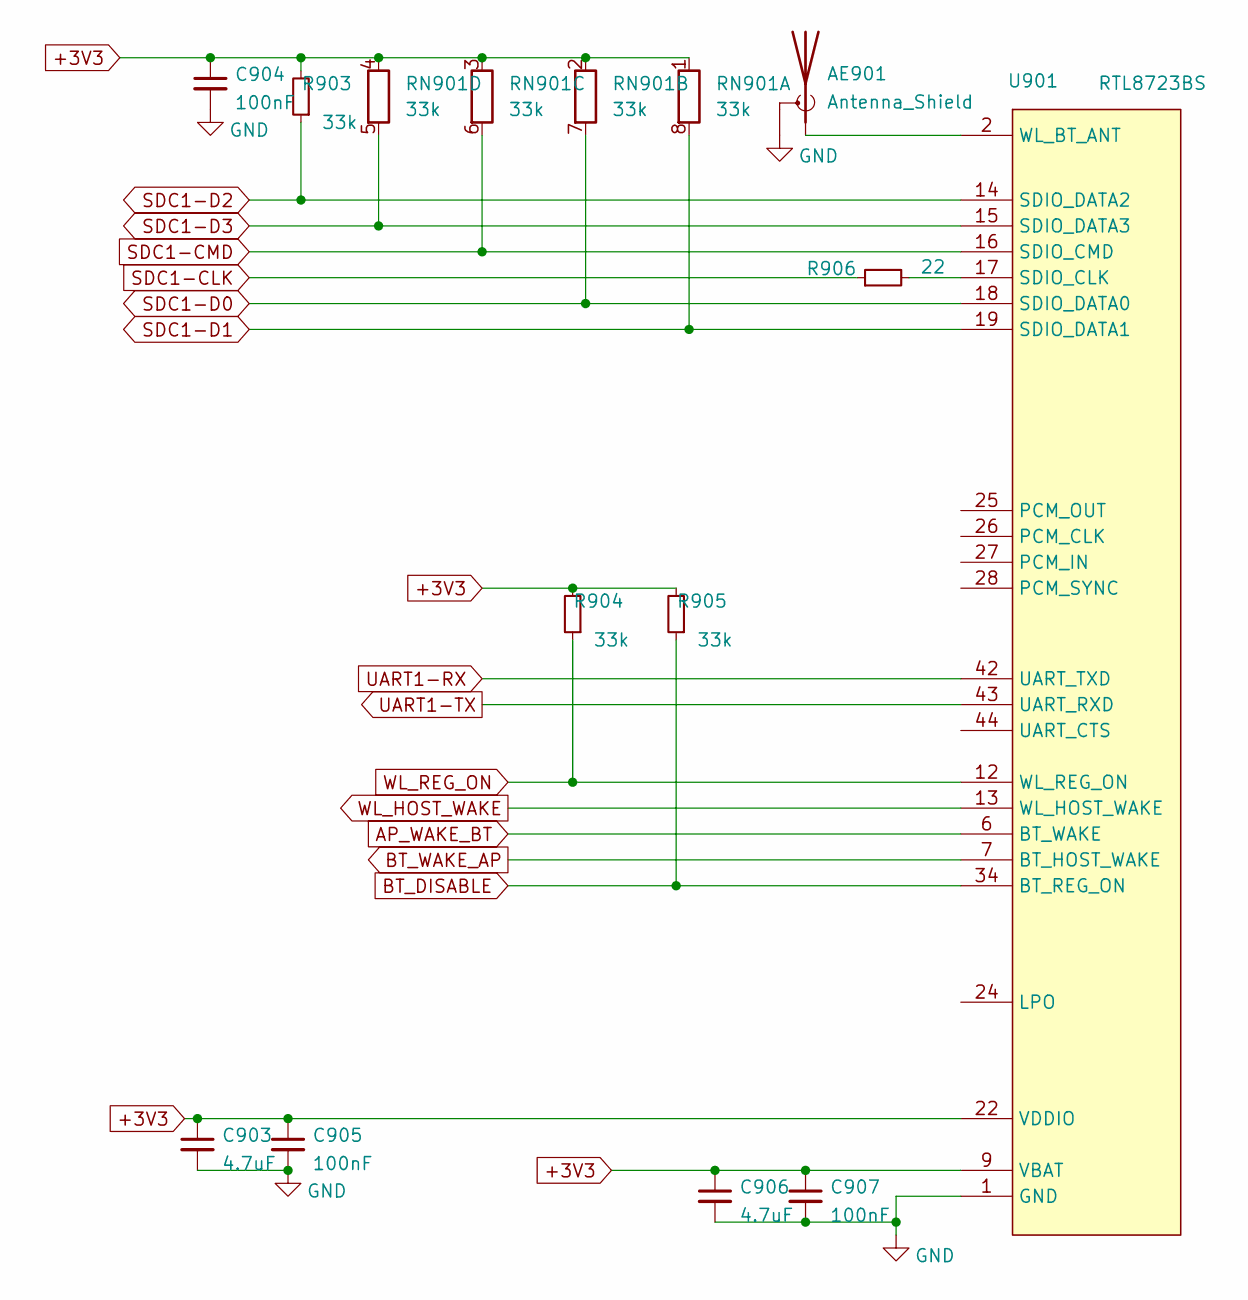
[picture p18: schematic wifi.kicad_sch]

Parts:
AE901: Antenna_Shield; U.FL_Hirose_U.FL-R-SMT-1_Vertical
C903, C906: 4.7uF; C_0603_1608Metric
C904, C905, C907: 100nF; C_0402_1005Metric
R903, R904, R905: 33k; R_0402_1005Metric
R906: 22; R_0402_1005Metric
RN901: 33k; R_Array_Concave_4x0402
U901: RTL8723BS; lga44_12x12mm_P0.9

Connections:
+3V3: C903.1, C904.1, C905.1, C906.1, C907.1, R903.2, R904.2, R905.2, RN901.1 (R1.1), RN901.2 (R2.1), RN901.3 (R3.1), RN901.4 (R4.1), U901.9 (VBAT), U901.22 (VDDIO); also elsewhere on the board
AP_WAKE_BT: U901.6 (BT_WAKE); also elsewhere on the board
BT_DISABLE: R905.1, U901.34 (BT_REG_ON); also elsewhere on the board
BT_WAKE_AP: U901.7 (BT_HOST_WAKE); also elsewhere on the board
GND: AE901.2 (Shield), C903.2, C904.2, C905.2, C906.2, C907.2, U901.1 (GND), U901.3 (GND), U901.20 (GND), U901.31 (GND), U901.33 (GND), U901.36 (GND), U901.41 (GND); also elsewhere on the board
unnamed: AE901.1 (A), U901.2 (WL_BT_ANT)
unnamed: R906.2, U901.17 (SDIO_CLK)
SDC1-CLK: R906.1; also elsewhere on the board
SDC1-CMD: RN901.6 (R3.2), U901.16 (SDIO_CMD); also elsewhere on the board
SDC1-D0: RN901.7 (R2.2), U901.18 (SDIO_DATA0); also elsewhere on the board
SDC1-D1: RN901.8 (R1.2), U901.19 (SDIO_DATA1); also elsewhere on the board
SDC1-D2: R903.1, U901.14 (SDIO_DATA2); also elsewhere on the board
SDC1-D3: RN901.5 (R4.2), U901.15 (SDIO_DATA3); also elsewhere on the board
UART1-RX: U901.42 (UART_TXD); also elsewhere on the board
UART1-TX: U901.43 (UART_RXD); also elsewhere on the board
WL_HOST_WAKE: U901.13 (WL_HOST_WAKE); also elsewhere on the board
WL_REG_ON: R904.1, U901.12 (WL_REG_ON); also elsewhere on the board

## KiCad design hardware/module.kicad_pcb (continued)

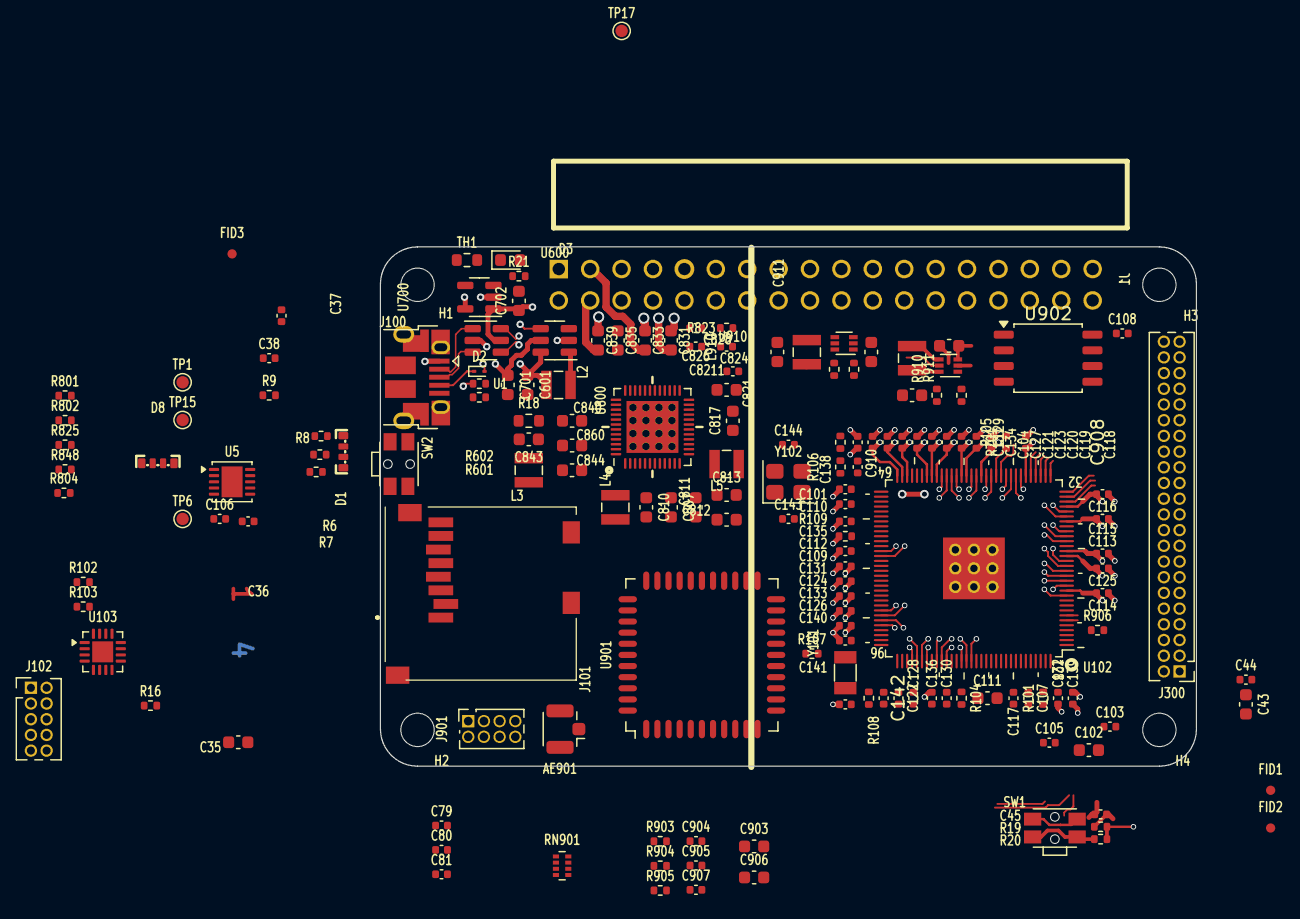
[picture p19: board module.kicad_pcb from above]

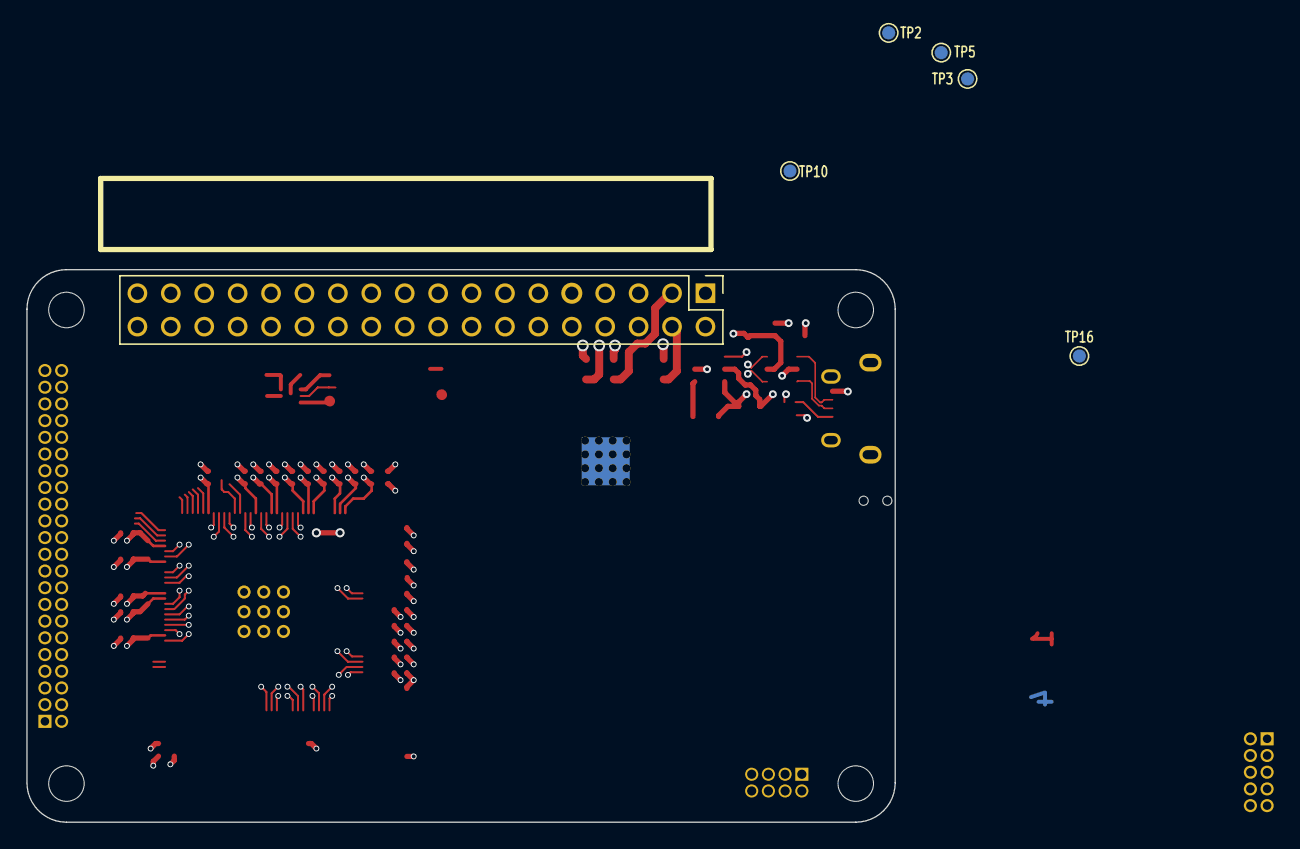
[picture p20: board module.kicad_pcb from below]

Board: 4 copper layers, 66.0 x 42.0 mm, 171 parts (6 on the bottom side), 137 nets.

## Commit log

2019-01-22 repo bringup
    [v3s-v0.1.0.brd, v3s-v0.1.0.sch, v3s-v0.1.1.brd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]
2019-05-02 project: updated structure
    [module.brd, module.sch, v3s-v0.1.0.brd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]
2019-05-15 board: updated flooplan
    [module.brd, module.sch]
2019-05-17 board: added nvm storage
    [module.brd, module.sch]
2019-05-17 defined power stage
    [module.brd, module.sch]
2021-10-04 switch to kicad
    [module.brd, module.sch]
2021-10-06 updates on features and layout
    [cpu.kicad_sch, io.kicad_sch, module.kicad_pcb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]
2021-10-10 improve component placement
    [module.kicad_pcb]
2021-10-16 added proper pmic
    [cpu.kicad_sch, module.kicad_pcb, module.kicad_sch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]
2021-10-23 upadted dimensions and component positions
    [cpu.kicad_sch, io.kicad_sch, module.kicad_pcb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]
2021-10-23 cosmetic fixes
    [cpu.kicad_sch, module.kicad_pcb, module.kicad_sch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]
2021-10-24 swap pmic section with axp203
    [cpu.kicad_sch, module.kicad_pcb, module.kicad_sch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]
2021-10-25 added 3d models
    [module.kicad_pcb]
2021-10-26 arranged parts for pmic
    [module.kicad_pcb]
2021-11-01 routed axp203 and optimized component footprints
    [module.kicad_pcb, module.kicad_sch, power.kicad_sch]
2021-11-13 small fixes
    [module.kicad_pcb]
2022-01-04 prepare for component reposition
    [cpu.kicad_sch, io.kicad_sch, module.kicad_pcb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]
2022-01-10 change component layout
    [cpu.kicad_sch, io.kicad_sch, module.kicad_pcb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]
2022-01-10 defined cpu connections
    [cpu.kicad_sch, io.kicad_sch, module.kicad_pcb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]
2022-01-11 routed lcd signals
    [cpu.kicad_sch, io.kicad_sch, module.kicad_pcb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]
2022-01-14 routed lcd bus
    [io.kicad_sch, module.kicad_pcb, module.kicad_sch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]
2022-01-16 add layer identification labels
    [module.kicad_pcb]
2022-01-25 small layout tweaks
    [module.kicad_pcb]
2022-01-29 remove lcd fpc connector
    [io.kicad_sch, module.kicad_pcb, module.kicad_sch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]
2022-01-30 add datasheet and new lcd connector
    [io.kicad_sch, module.kicad_pcb, module.kicad_sch]
2022-02-25 change cpu footprint
    [io.kicad_sch, module.kicad_pcb, module.kicad_sch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]
2022-03-08 try new component placement
    [module.kicad_pcb]
2022-03-24 add axp203 aux parts
    [cpu.kicad_sch, module.kicad_pcb, module.kicad_sch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]
2022-03-28 routing work
    [cpu.kicad_sch, io.kicad_sch, module.kicad_pcb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]
2022-03-29 added more testpoints
    [module.kicad_pcb, module.kicad_sch, power.kicad_sch]
2022-03-30 add 5v otg support components
    [module.kicad_pcb, module.kicad_sch, power.kicad_sch]
2022-04-16 add board render
2022-05-03 add spi flash for boot
    [cpu.kicad_sch, module.kicad_pcb, module.kicad_sch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]
2022-05-04 finish lcd bus
    [cpu.kicad_sch, module.kicad_pcb, module.kicad_sch]
2022-05-06 prepare wifi section and io exp
    [cpu.kicad_sch, module.kicad_pcb, power.kicad_sch]
2022-05-07 add wifi parts
    [cpu.kicad_sch, io.kicad_sch, module.kicad_pcb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]
2022-05-07 add missing 3d models
    [module.kicad_pcb]
2022-05-07 add port expander for additional gpio
    [cpu.kicad_sch, module.kicad_pcb, module.kicad_sch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]
2022-05-12 define lcd connector pins
    [cpu.kicad_sch, io.kicad_sch, module.kicad_pcb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]
2022-05-13 add port expander connections
    [cpu.kicad_sch, io.kicad_sch, module.kicad_pcb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]
2022-05-22 fix ethernet header for compatibility
    [io.kicad_sch, module.kicad_pcb, module.kicad_sch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]
2022-05-26 more routing work
    [module.kicad_pcb]
2022-05-26 fix audio connector
    [cpu.kicad_sch, module.kicad_pcb]
2022-05-26 finished routing
    [cpu.kicad_sch, module.kicad_pcb, module.kicad_sch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]
2022-06-16 updated board
    [module.kicad_pcb]
2022-07-10 prepare first release for fab
    [io.kicad_sch, module.kicad_pcb, module.kicad_sch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]
2024-03-08 new layout
    [cpu.kicad_sch, io.kicad_sch, module.kicad_pcb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]
2026-01-04 prepare for rev2
    [cpu.kicad_sch, io-exp.kicad_sch, io.kicad_sch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]
2026-01-26 placed decoupling caps
    [cpu.kicad_sch, io-exp.kicad_sch, module.kicad_pcb]
2026-04-22 backport changes
    [cpu.kicad_sch, io-exp.kicad_sch, module.kicad_pcb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]

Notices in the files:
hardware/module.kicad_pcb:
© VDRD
